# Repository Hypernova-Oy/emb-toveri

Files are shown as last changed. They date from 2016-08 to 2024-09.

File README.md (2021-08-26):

# emb-toveri
Weatherproof embedded user authenticator and authorizator device

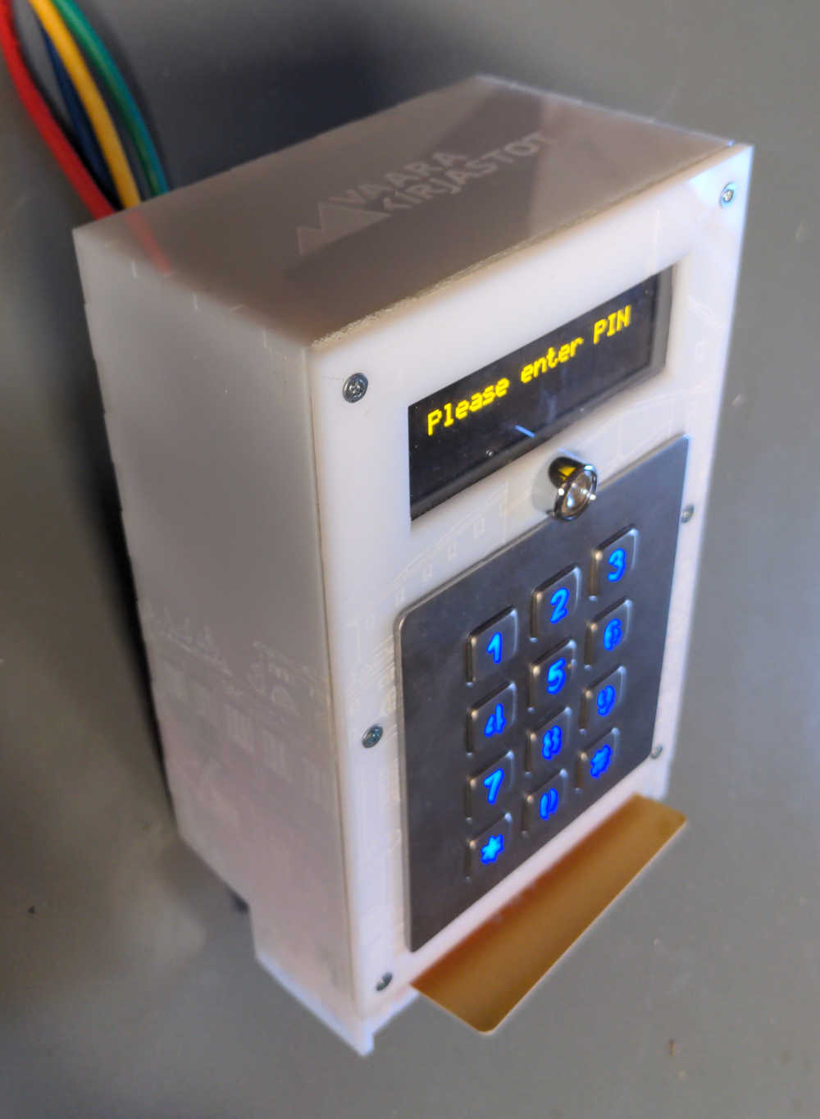
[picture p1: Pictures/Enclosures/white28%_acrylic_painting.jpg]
Toveri_PIN_entry


## Skills needed to build a working Toveri

From front-end to backend

- [GNU gettext](https://www.gnu.org/software/gettext/)
- [Perl](https://www.perl.org/)
- [REST API](http://www.restapitutorial.com/)
- [HiPi](http://raspberrypi.znix.com/hipidocs/)
- [Swig](http://www.swig.org/papers/Perl98/swigperl.htm)
- [C](http://www.cprogramming.com/)
- [SPI](https://en.wikipedia.org/wiki/Serial_Peripheral_Interface_Bus)
- [Ansible](http://docs.ansible.com/)
- [Raspberry Pi](https://www.raspberrypi.org/)
- [Linux](https://www.linuxfoundation.org/)
- [KiCad](http://kicad-pcb.org/)
- [Blender](https://www.blender.org/)
- [Soldering](https://www.youtube.com/watch?v=vIT4ra6Mo0s)
- [Electronic assembly](https://duckduckgo.com/?q=genuino+starter+kit&t=canonical&ia=products)

## Estimated steps to production

* Ordering components from various suppliers (500-600€)
* Assembly of the PCB
* Soldering the PCB
* Making the cabling
* Disassembling and cleaning the 3D print
* Assembling the cables and components to the 3D-printed railing and enclosure.
* Installing Raspbian to the Raspberry Pi
* Setting up internet/network access
* Accessing device via remote maintenance connection
* Configuring barcode reader by reading control codes by hand.
* Installing software
* Configuring software and Server REST API
* Running hardware diagnostics
* Running software diagnostics
* Planning the deployment location
  - Proper accessible position
  - Network access
    - Toveri has a remote maintenance connection using ssh, typically this requires some firewall rules to allow inbound traffic to Toveri's port :TCP22
    - Toveri needs access to the Koha's REST API, typically at port :TCP443
    - Additionally a monitoring solution, such as Zabbix, needs extra inbound/outbound ports to be forwarded. This is outside the scope of this project.
  - Power utility access
  - Maximum distance between the exterior barcode reader and Raspberry Pi is 4m of cable.
  - Safe location for the Raspberry Pi in the interior space.
  - How to attach the device to the exterior wall?
* Executing the deployment plan
* Monitoring performance and logs
* Getting reports of device usage
* Maintenance

## Documentation

* Blender/README.md: Instructions on how to read the electronic enclosure and connection railing schematics.

* KiCad/README.md: Instructions on how to read the electronic diagrams.

* ASSEMBLY.md: Component manifest and supplier list.

* [more here](Documents/)

## Some pics about the finished Toveri

Previous enclosures
Old models

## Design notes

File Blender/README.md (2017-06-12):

In this directory:
------------------

Blender models and measurements of the electronic enclosure and connection railings.
Each component is on its own layer to easily identify needed components.

Uses the excellent MeasureIt-plugin for Blender. Enable it before loading these schematics.

Then go to the MeasureIt-submenu and show measurements.

Toveri3D_printable.blend Toveri3D_printable.stl toveri.blend

FILES:
  Toveri3D_printable.stl contains all the pieces you need. All the separate pieces are readily assembled to be 3D printed.
  Author recommends Shapeways.com and their "White Strong and Flexible"-material for verified results.

  toveri.blend is the master 3D-model with all relevant components modelled.
  It helps a lot when designing the interior space usage.

  screw\ profiles.blend contains the https://en.wikipedia.org/wiki/ISO_metric_screw_thread profiles used in the
  model to print the screw threads. Screw threads help a lot when assembling all the components.

  Other *.blend-files are legacy models and are preserved for historical purposes. They should be fully usable as well,
  if you for some reason prefer older designs.

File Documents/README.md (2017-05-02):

This directory contains various documents related to the lifecycle of emb-toveri.

- Enclosure_1550K-26634.pdf
  The schemtic of the electronic enclosure where Toveri assembled into. Is missing the barcode guide, but
  it only adds ~3cm of extra height.

- DatalogicGryphonGFS4400ReferenceManual820049614RevC.pdf
  Reference manual for programming and using the barcode reader

- barcodeReaderManualConfigurationCodes.png
  You must manually configure the communication protocol for each barcode reader. Other aspects are automatically
  configured whenever Toveri boots.

- Physical_install_FI.odt
  A case example of how to install Toveri to the Eno library.
  Maybe some day will be a complete physical installation guide.

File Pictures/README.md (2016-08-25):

In this directory:
------------------

All images used.

Including printable logos and instructables.

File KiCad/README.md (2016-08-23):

In this directory we present the KiCad electronic schematics you need to assemble this device.

- toveri-directory has the master schematics for all the needed hardware components.

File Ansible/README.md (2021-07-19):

# Toveri software installation and management.

## 0. Prepare the central controller

Toveri-network is managed from one central controller. It automates software provisioning for the Raspberry PIs and management of configuration.

0. Choose a location for your central controller. For testing and assembly purposes it can be a local PC, or a virtual server in the cloud, or anything in between.

1. Install Ubuntu

2. Get the source code

`$> git clone https://github.com/Hypernova-Oy/emb-toveri.git`
`$> cd emb-toveri/Ansible`

3. Install the central controller

`$> sudo bash makefile.sh`

## 1. Provisioning a Raspberry PI

### Prepare the operating system

1. Install Raspbian lite.

2. Run the ansible_slave_driver.sh.gpg in the Raspberry Pi. (see the next step)

### Provision the software from the central controller

#### 1. Add a new Toveri to the central controller

`ansible-playbook -vvvv toverit_provision_new.playbook`

or if you want to provide the configuration from the CLI

`ansible-playbook -vvvv toverit_provision_new.playbook -e max_toveri_port=53518 -e toveri_organization_name=vaara -e toveri_name=liperi`

#### 2. Edit the new configuration and the new vault

#### 3. Run the bootstrap-script in the Raspbian

Copy the encrypted ~/secret/ansible_slave_driver.sh.gpg to the destination Raspbian OS, and run it there, to make the Raspian connect to the central controller.

#### 4. Provision with Ansible

`ansible-playbook toverit.playbook`

## 2. Managing the infrastructure

1. Edit Ansible configuration files

2. Provision with Ansible

`ansible-playbook toverit.playbook`

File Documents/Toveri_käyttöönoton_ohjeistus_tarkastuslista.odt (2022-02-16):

Toveri:n käyttöönoton ohjeistus ja tarkastuslista

# Koha-asennuskohtaiset yhteiset pelisäännöt

Kun Koha-asennuksessa päätetään siirtyä omatoimiaikaan, on sovittava yhteisistä omatoimen pelisäännöistä. On tärkeää pyrkiä yhteisiin käytäntöihin. Tämä on kaikista selkeintä asiakkaillemme, halki kuntarajojen.

Toveri käyttää Kohan itsepalveluoikeuden tarkastusrajapintaa,

- /api/v1/borrowers/ssstatus

joka parametroidaan Kohassa järjestelmäasetuksilla ‘SSRules’ ja ‘OpeningHours’. Toveri noudattaa siis Kohan säädöksiä, ja pelkästään muistaa kävijöiden käyttöoikeustilanteen.

Asetukset on dokumentoitu Kohan pääkäyttäjätyökalussa.

# Kirjaston fyysinen laitteen asennus

Toverin asennus vaatii onnistuakseen usean toimijan yhteistyötä. Monta asiaa pitää huolehtia ennen Toverin asentamista kohteeseen. Ennakkoon asioiden hoitaminen on oleellista, koska avainhenkilöt eivät ole aina tavoitettavissa, tai voivat äkillisen syyn takia olla estyneitä, asennusajankohdassa. Lisäksi asioiden hoitaminen paikan päällä lisää Toveri-asentajan työmäärää asennuspaikassa ja voi viivästyttää asennuksen monipäiväiseksi.

Asennuksen valmistelussa kannattaa ottaa hyvät valokuvat asennuskohteesta. Videopuhelun avulla saa hyvän käsityksen asennuskohteesta ja oikeiden asennuspaikkojen valinta onnistuu sitäkin kautta. Valokuviin tehtyjen merkintöjen avulla on helppo kommunikoida asennus/työtarpeet kaikille osapuolille. Turha matkustaminen asennuskohteisiin on kallista ennenkaikkea työn tilaajalle.

## Asennuspaikka

Ulkopuolen asennuspaikan pitää olla esteettömästi saavutettava, mistä esim pyörätuolilla on mahdollista päästä avatusta ovesta sisään järkevässä ajassa. Asennuspaikan ei tarvitse olla suojassa kosteudelta, sillä Toveri on vedenpitävä ylhäältä ja sivuilta tulevaa kosteuskuormaa vastaan.

Katso Läpiviennit-kohdsta rajoitteet paikan valintaan.

## Älylaitteen sijainti

Sisäpuolelle asennettava älylaite (Raspberry Pi) on laitettava sellaiseen paikkaan, missä asiakkaat eivät pääse helposti sitä räpläämään. Älylaite on suojattu helpolta sorkkimiselta, mutta on mahdollista hakkeroida Älylaite poistamalla muistikortti, muokkaamalla sitä ja asettamalla se takaisin paikoilleen.

Älylaitteen ja Toverin välinen maksimietäisyys on 5m RJ45-kaapelia, koska tällöin voidaan käyttää yksinkertaista kaapelointia eikä erillisiä signaalinvahvistimia tarvita.

## ATK-pistoke ja kaapelin veto talojakomoon

Toveri tarvitsee yhden RJ45-pistokkeen (ATK-pistoke), joka pitää kytkeä talojakomon reitittimeen. Sähkömies asentaa nämä yhdessä kirjaston edustajan kanssa sovittuun paikkaan lähelle Toverin älylaitetta.

## Verkkovirtapistokkeet

Toveri tarvitsee verkkovirtapistokkeen. Sähkömies asentaa nämä yhdessä kirjaston edustajan kanssa sovittuun paikkaan lähelle Toverin älylaitetta. Tarvittaessa voidaan käyttää jatkojohtoa.

## Läpiviennit

Rakennuksen ulkoseinästä pitää porata 25mm halkaisijalla oleva läpivienti sisätilaan Toverin kaapelointia varten. Läpivienti tulee ulkoseinän puolelta mitattuna 115cm korkeudelle lattiasta/maasta. Läpiviennin tekemisessä pitää huomioida helppo sisäpuolen peitettävyys kaapelikotelolla tai muu tapa verhoilla rumat jäljet.

Lisäksi on tärkeää porata läpivienti siten, että se kallistuu alaspäin ulkoseinän puolelle pari astetta, jolloin sadevesi ei pääse valumaan läpivientiä pitkin rakenteisiin. Lisäksi sähköputken ja seinän välinen rako on syytä tiivistää tiivistysmassalla.
Läpiviennin sisälle asennetaan 25mm halkaisijalla oleva sähkö/asennusputki, joka tulee 25mm ulkoseinästä ulospäin, ja 0mm sisäseinästä ulospäin.

Toveri asetetaan sähköputken päälle siten, että putken pää menee Toverin keskiosasta sisäpuolelle, muodostaen vesitiiviin liitoksen.

## Sähkölukkokytkentä

Toveri ohjaa sähkölukkoa ulkoisen releboksin kautta, josta on valmiina ulkona kaksi merkattua piuhaa, joihin sähkölukko kytketään. Toveri sulkee releen ohjaaman potentiaalivapaan virtapiirin oven avaamisen merkiksi.

Sähkölukkokytkennässä pitää sopia sähkölukon toimittajan kanssa:

- Vastaako sähkölukon toimittaja vai Toveri, omatoimikirjaston sähkölukittavien ovien auki pitämisestä normaaleina aukioloaikoina?
- Antaako Toveri sähkölukolle avaussignaalin, vai pitääkö Toverin pitää ovirelettä suljettuna niin kauan kuin sähkölukittuja ovia halutaan pitää auki?

## Kaapeleiden kotelointi

Kaapeleille pitää suunnitella sisäpuolelle reitti miten ne viedään Älylaitteelle. Reitti pitää pystyä koteloimaan tai verhoilemaan siististi.

Kaapelikotelon läpimitoiksi riittää 30x10mm, tyypillisesti 4m kaapelikoteloa riittää asennuskohdetta kohden.

## Älylaitteen verhoilu

Älylaitteen ympärille muodostuu valtava piuha- ja muuntajahärdelli. Se on syytä verhoilla, esim. nätilla IKEA:n kaapilla tai puisella verhoilulevyllä. Älylaitteelle on tarpeellistä päästä tekemään huoltotoimenpiteitä, joten verhoilu/kaappi pitää olla avattavissa.

Usein verhoilua pääsee suunnittelemaan vasta sitten kun Toveri on jo asennettu. Voi olla vaikea arvioida mihin mm. tilatut pistokkeet tarkalleen asentuvat.

## Palomuuriavaukset ja etähuoltoyhteys

Älylaitteesta pitää saada muodostettua yhteys Koha-palvelimen porttiin :TCP443 asiakkaan omatoimikelpoisuuden tarkistamiseksi.

Älylaitteesta pitää saada muodostettua yhteys julkiseen internetiin porttiin :TCP22 Toveri-keskuspalvelimen huoltoyhteyttä varten. Älylaite avaa käänteisen huoltotunnelin käyttäen turvallisia ssh-avaimia, jota pitkin keskuspalvelimelta saadaan muodostettua yhteys.

Älylaite tarvitsee normaalin pääsyn internetiin erilaisten ohjelmisto-, sekä käyttöjärjestelmäpäivitysten hakemiseksi.

Toveri ei tarvitse kiinteää (julkista tai sisäverkon) IP-osoitetta, mutta sellainen voidaan tarvittaessa asettaa paikallisten verkkoliikennekäytänteiden mukaisesti.

Palomuuriavauksista on syytä huolehtia hyvissä ajoin, sillä niiden toimivuudessa on ollut historiallisesti haasteita.

Palomuuriavaukset pitää testata etukäteen, tai ainakin varoittaa verkkoliikenteestä vastaavia tahoja asennusajankohdasta, että vastaavat puhelimeen.

# Kirjastokohtaiset Toverin asetukset

Koha-asennus (organisaatio) -kohtaisten määrittelyjen lisäksi, jokainen Toveri pitää parametroida toimimaan kirjastokohtaisesti optimaalisesti.

## Toverin kotelon ja kaiverrusten valinta

Jokaiselle Toverille tehdään meidän tehtalla oma kotelo. Asiakas voi valita yhteistyökumppanimme materiaalipankista:

https://cotter.co/materials/

haluamansa värin ja materiaalin, seuraavin rajoituksin:

- Huom, neon-acrylic on läpinäkyvää akryyliä.

- Ulkotiloihin vain polykarbonaatti tai akryyli, paksuus 3mm.
- Sisätiloihin käy myös puiset materialit

Toveriin saa omat kaiverrukset. Yksinkertaiset logot kuuluvat tarjoukseen.
Koteloon voidaan kaivertaa esimerkiksi Akseli Gallen Gallelan Kalevala-aiheisia maalauksia tai joku teidän kirjastollenne tärkeä asia, johon teiltä tekijänoikeus löytyy.

Jos kaiverrukset ovat erityisen vaativia, pyydetään lisähintaa tarjouksen mukaisesti.

Toimita logot ja kuvat mieluiten vektorigrafiikkaformaatissa. Tarvittaessa me hoidamme kuvien muuntamisen kaiverrusmuotoon, sekä yksinkertaistamme niitä laserkaiverrukseen sopivaksi.

Esimerkkejä kaiveruksista ja koteloista löytyy täältä:
https://github.com/Hypernova-Oy/emb-toveri/tree/master/Pictures/Enclosures

Kotelon laserleikkausprofiili löytyy täältä:

https://github.com/Hypernova-Oy/emb-toveri/blob/master/FreeCAD/Toveri-3mm-acrylic.svg

## Sähkölukon avaussignaalin pituus

Riippuen siitä pitääkö Toverin pitää sähkölukko auki, vai antaako Toveri signaalin taloautomaatio-ohjelmistolle, pitää määrittää miten pitkään Toverin ovenavausrele antaa ohjaussignaalia sähkölukolle.

Jos Toveri ohjaa sähkölukkoa suoraan, ohjaussignaalin pituus on se aika kun sähkölukot pysyvät auki hyväksytyn asiakkaan tunnistautumisen jälkeen.

Jos Toveri antaa ohjaussignaalin taloautomaatio-ohjelmalle, lyhyt 1000ms impulssi riittänee.

ks. kappale “Sähkölukkokytkentä”

## Omatoimiajat

Jokaiselle kirjastolle pitää määritellä se omatoimiaika, jolloin Toveri päästää uusia asiakkaita sisään.

Tämä määrittely tapahtuu Kohassa.

Toveri ei aja asiakkaita pois omatoimiajan päätyttyä.

Parempi on mitä vähemmän poikkeuksia omatoimen aukioloajoissa on. Suositellaan, että käytetään säännöllisiä viikkoaukioloja, joka päivä, riippumatta erikoisista juhlapyhistä.

## Toveri-käyttäjä Kohassa

Jokainen Toveri tarvitsee laitekohtaisen käyttäjä/asiakastilin Kohassa.

Käyttäjälle pitää määritellä seuraavat asiat:

- Asiakaslaji on automaatti tai vastaava
- Käyttäjätunnus on mallia ‘toveri.KIRJASTOKOODI’
- Toveri -käyttäjätilin kirjasto on asetettu oikein.
- Käyttäjätilin API-avain on luotu ja toimitettu Toveri-asentajalle. API-avaimen voi luoda virkailijatyökalussa osoitteessa [Etusivu › Asiakkaat › API-avaimet] ‘/cgi-bin/koha/members/apikeys.pl’
- Käyttäjätilille on annettu oikeus ‘borrowers.get_self_service_status’
- Omatoimikirjastopisteelle on asetettu viikoittaiset aukioloajat Kohan järjestelmäasetukseen ‘OpeningHours’.

# Kirjastokohtaiset omatoimipalvelun muut asiat

Tässä kappaleessa kuvataan Toveri-asennuksen ja määrittelyn ulkopuolisia asioita, joita kirjaston on syytä ottaa huomioon asennuskohteessaan.

## Miten asiakkaat ajetaan pois omatoimiajan päätyttyä?

Käytetäänkö aikaohjattuja valoja?
Onko kuulutuksia?

Missä aikaohjauksien aikatauluja ylläpidetään? Käyttöönoton tarkastuslomake

Ohessa on listattu kuvatut toimenpiteet, joista pitää huolehtia, että Toveri saadaan onnistuneesti asennettua.

Taulukot noudattelee RACI (https://fi.wikipedia.org/wiki/RACI)-tapaa.

## Taulukon lyhenteiden selitykset ja yhteystiedot

R - “Kuka vastaa/tekee”-sarake. Kuka vastaa asian hoitamisesta tai delegoinnista käytännön tasolla.

A- “Kuka on vastuussa” -sarake.

C - “Ketä on konsultoitava” -sarake. Keneltä on kysyttävä mielipide.

I - “Ketä on tiedotettava” -sarake. Kenelle on kerrottava työn edistymisestä.

Rooli | Kuvaus | Vastuuhenkilön yhteystieto
Koha | Kohan pääkäytäjä
Toveri | Toverin toimittaja
KH | Kiinteistöhuolto
PH | Projektinhallinta
Ovi | Sähköovien toimittaja
ICT | Verkko- ja tietoliikennetuki

## Laitteen asennus

Tehtävä | R | A | C | I
Onko Kohaan parametroitu omatoimen käyttösäännöt? | Koha | PH | Kir
Miten meni?
Onko Toverin asennuspaikka valittu ulkopuolelle? Onko se saavutettavissa? Onko se esteettinen? | Kir Toveri | PH | KH
Miten meni?
Onko Älylaitteen paikka valittu sisääpuolelle? Onko se epäsaavutettavissa? Yltääkö kaapelit Toverista Älylaitteeseen? | Kir Toveri | PH | KH
Miten meni?
Onko ATK-pistoke Älylaitteelle ja verkkokaapelin veto talojakomoon tilattu? | KH | PH
Miten meni?
Onko ATK-pistoke ja verkkopiuha asennettu? | KH | PH
Miten meni?
Onko verkkovirtapistoke tilattu? | KH | PH
Miten meni?
Onko verkkovirtapistoke asennettu ja tuleeko virtaa? | KH | PH
Miten meni?
Onko läpiviennit tilattu? | KH | PH | Toveri
Miten meni?
Onko läpiviennit toteutettu? | KH | PH
Miten meni?
Onko sähkölukkokytkennästä sovittu sähkölukon toimittajan kanssa? | Ovi | PH | Toveri KH
Miten meni?
Onko kaapeleiden reitti tiedossa? Onko kotelointi suunniteltu? | Toveri | PH | KH Ovi
Miten meni?
Onko verhoilu suunniteltu? | Kir | PH | KH Toveri
Miten meni?

Onko verhoilu tehty? | KH tai Toveri | PH
Miten meni?
Onko palomuuriavaukset tilattu? | Kir | PH | Toveri
Miten meni?
Onko palomuuriavaukset tehty? | ICT | PH
Miten meni?
Onko palomuuriavaukset testattu? | Kir | PH | Toveri ICT
Miten meni?
Onko asennusajankohta sovittu yhdessä sidosryhmien kanssa? | Toveri | PH | Kir, ICT, Ovi, KH
Miten meni?
Asennuksen toteuttaminen | Toveri | PH | Kir, ICT, Ovi, KH
Miten meni?
Koulutuksen järjestäminen | Toveri | PH | Kir
Miten meni?

## Kirjastokohtaiset Toverin asetukset

Tehtävä | R | A | C | I
Miten pitkään sähkölukkoa pidetään avoinna? | Toveri | PH | Ovi
Miten meni?
Mitkä ovat toimipisteen aukioloajat? | Koha | PH | Kir
Miten meni?
Kohaan on lisätty Toverille oma asiakas/käyttäjätili kohdan Toveri-käyttäjä Kohassa mukaisesti. | Koha | PH | Kir | Toveri
Miten meni?

## Kirjastokohtaiset omatoimipalvelun muut asiat

Tehtävä | R | A | C | I
Miten asiakkaat ajetaan pois omatoimiajan päätyttyä? | Toveri | PH | Ovi
Miten meni?

# Takuuvaiheen vastuut ja yhteystiedot

RACI-taulukot noudatavat samaa kaavaa kuin kappaleessa #Käyttöönoton tarkastuslomake.

Yhteystiedot samat kuin kohdassa #Käyttöönoton tarkastuslomake.

Tehtävä | R | A | C | I
Toveri toimii oikein: Lukee asiakkaan tunnisteen ja piippaa merkiksi onnistuneesta lukukerrasta. Näyttää tietoja näytöllä Ovenavausrele “napsahtaa” kun ovenavaussignaali annetaan Kirjaston henkilökunta ilmoitusvelvollisia havaituista puutteista. | Toveri Kir | Toveri | Kir | Kir Toveri
Verkkoyhteys toimii: Etäyhteys Toveriin saada muodostettua Toveri saa poimittua päivän blokkilistan Koha-palvelimelta Toveri saa reaaliaikaiset käyttöoikeustiedot Koha-palvelimelta | ICT | Kir | Toveri
Sähköä on tarjolla | KH | | | Toveri
Koha on parametroitu oikein: Järjestelmäasetukset ok Asiakkaan luvat ja tiedot päivitetty asiakastiliin Koha vastaa rajapintakutsuihin ja toimittaa blokkilistan | Koha | Kir | | Toveri

## Toveri-vikaselvitysprosessi

Tyypillisesti vikatilanteessa toimitaan seuraavanlaisesti.

1. Virkailija tai kirjaston käyttäjä huomaa vikatilanteen.
2. Ilmoitetaan Hypernovan Toveri-yhteyshenkilölle sähköpostilla, tai hätätilanteessa puhelimitse.
3. Toveri-yhteyshenkilö tarkastaa tilanteen etäyhteyden kautta ja ajaa laitediagnostiikat, yhdessä kirjaston yhteyshenkilön kanssa. Selvitetään onko vika Toverissa vai jossain muualla ja mikä on vian vakavuusaste.
4. Jos etäyhteyden kautta vikaa ei saada korjattua, käydään laite huoltamassa tai vaihtamassa uuteen.

# Versiohistoria

2018-11-15 – Ensimmäinen versio

2019-06-25 – Lisätty “Kirjastokohtaiset Toverin asetukset → Toveri-käyttäjä Kohassa → ‘OpeningHours’”
2020-09-08 – Laajennettu läpivienti 30mm
2020-10-29 – Custom-kotelointiohjeet lisätty

2022-02-16 – Palautettu läpiviennin halkaisija 25mm. Täsmennetty läpiviennin ohjeita. Pieniä korjauksia.

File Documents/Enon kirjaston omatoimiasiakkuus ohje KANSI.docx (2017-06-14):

Ongelma- ja hätätilanteen

Kirjaston käyttöön liittyvissä ongelmatilanteissa ota yhteyttä mihin tahansa avoinna olevaan Vaarakirjastojen toimipisteeseen puhelimitse. Puhelinnumerot löytyvät mm. lainaus-palautusautomaatin kyljestä. Toivomme, että omatoimiajalla ilmenneistä ongelmista kerrotaan myös Enon kirjaston henkilökunnalle joko henkilökohtaisesti palveluajalla, kirjoittamalla palvelutiskillä olevaan viestivihkoon tai sähköpostitse: enonkirjasto@jns.fi


Hätätilanteet

Yleinen hätänumero 112
Kiinteistönhuollon päivystys 044 576 7402

Yhteystiedot

Enon kirjasto
050 469 8722 / palvelutiski
enonkirjasto@jns.fi

Joensuun pääkirjasto
050 406 5992 / lainausosasto
kirjasto@jns.fi

www.vaarakirjastot.fi

ASIOINTI OMATOIMIAIKAAN

# ENON KIRJASTOSSA

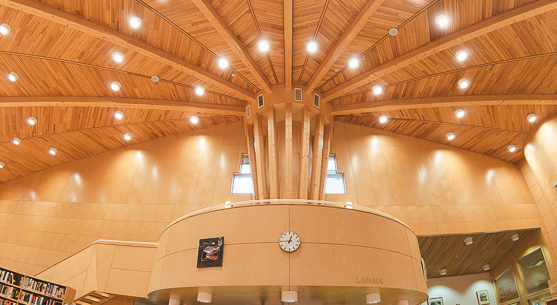
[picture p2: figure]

OMATOIMIAIKA KULKUKORTILLA

- ma-pe 07.00 – 20.00
- la ja su 08.00 – 16.00

PALVELUAIKA

- maanantai ja torstai

13.00 – 19.00

- tiistai, keskiviikko

ja perjantai 10.00 – 16.00

- aattoina 10.00 – 15.00

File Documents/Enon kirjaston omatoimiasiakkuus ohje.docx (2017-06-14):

# Omatoimiasiakkuus

Enon kirjastossa voi asioida omatoimiaikaan, eli

silloinkin kun henkilökunta ei ole paikalla.

Omatoimiasiakkaan tulee hyväksyä omatoimiasiakkuuden ehdot ja allekirjoittaa asiakassopimus. Asiakassopimus tehdään palveluaikaan kirjastohenkilökunnan työskennellessä Enon kirjastossa.

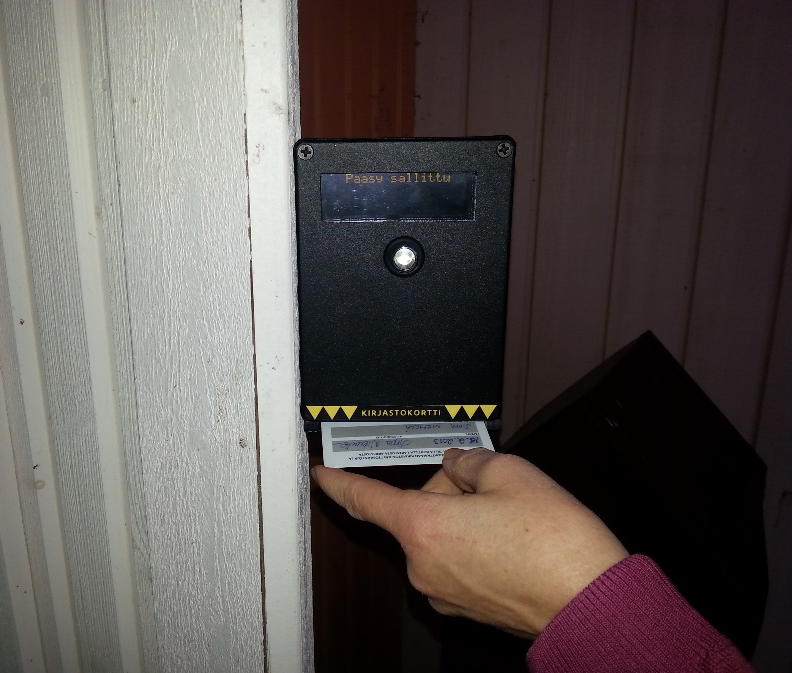
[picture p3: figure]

Asiakkaalla tulee olla voimassaoleva Vaara-kirjastojen kortti eikä asiakastiedoissa saa olla kirjaston käyttöön liittyviä rajoituksia. Alle 18 vuotiaiden asiakassopimukseen edellytetään myös huoltajan allekirjoitus.

Kun asiakassopimus on allekirjoitettu

ja omatoimiasiakkuuden oikeus tallennettu

kirjastojärjestelmään,

kirjaston ovi aukeaa kirjastokortilla

(viivakoodipuoli ylöspäin).

Omatoimiaika tarkoittaa sitä,

että henkilökunta ei ole palvelemassa,

neuvomassa ja opastamassa kirjastossa.

Lainaus- ja palautusautomaatin käytön opettelu

ja muu tutustuminen kirjastoon tapahtuu

palveluajalla.

Omatoiminen asiointi Enon kirjastossa

on mahdollista maanantaista perjantaihin klo 07:00-20:00.

Viikonloppuisin (lauantaina ja sunnuntaina) omatoimiasiointi on mahdollista klo 08:00-16:00 välisenä aikana.

Omatoimiajan päätyttyä ma-pe klo 20:00 ja la-su klo 16:00 hälytysjärjestelmä kytkeytyy automaattisesti päälle. Rakennuksesta on poistuttava ennen omatoimiasioinnin päättymisaikaa, sillä aiheettomista hälytyksistä peritään niiden aiheuttajalta maksu.




Kirjastossa on tallentava kameravalvonta.

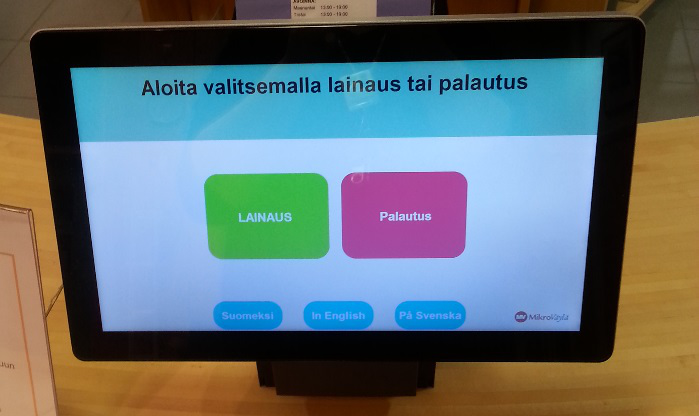
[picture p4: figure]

# Lainaus- ja

# palautusautomaatin käyttö

Automaatilla lainaamista varten

tarvitaan voimassa oleva kirjastokortti.
Palautettaessa kirjoja, kirjastokorttia ei tarvita.

Lainaus- ja palautusautomaatin käyttö on helppoa: se neuvoo koko ajan, mitä seuraavaksi tulee tehdä. Lue huolellisesti näytöllä olevat ohjeet kussakin vaiheessa.

Kirjastoaineistossa olevan viivakoodin tulee olla ylöspäin. Muuten koodin suunnalla ei ole väliä (sen voi laittaa myös poikittain tai vinottain). Viivakoodi on useimmiten niteen takakannessa, mutta voi olla myös etukannessa, tai takakannen sisäpuolella.

Kirjaston viivakoodit ovat aina tarroja ja niissä lukee kirjaston nimi.

HUOM! Kirjan kanteen painettu ISBN-tunnus ei ole kirjaston viivakoodi.

Mikäli aineiston viivakoodi ei toimi kun yrität lainata:
merkitse oman kirjastokorttisi numero sekä aineiston nidenumero (=viivakoodiraidan alla oleva esim. 167–alkuinen numerorivi) palvelutiskillä olevaan lomakkeeseen.

Lainattu aineisto on aina palautettava joko palveluaikana palvelutiskillä tai omatoimiajalla automaatin kautta. Palautusluukkua ei ole. Älä jätä palauttamatonta lainaa omatoimiajalla kirjaston pöydälle!

Mikäli aineiston viivakoodi ei toimi kun yrität palauttaa automaatilla:

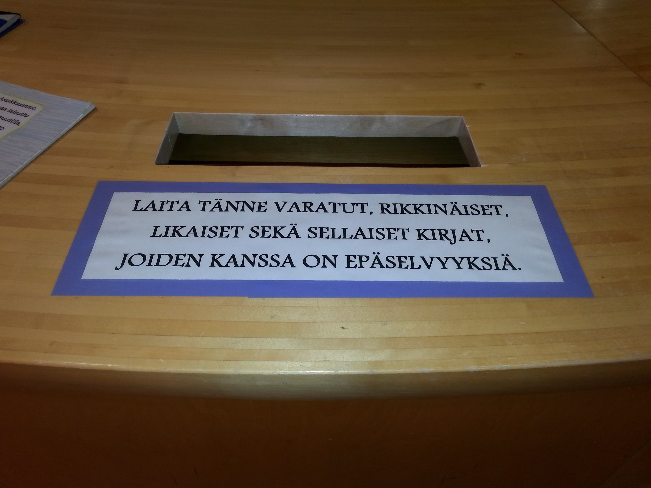
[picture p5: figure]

laita palautettava aineisto automaatin

vieressä olevasta aukosta palvelutiskin

alla olevaan lukolliseen palautuslaatikkoon.

Olet vastuussa lainasta siihen saakka kunnes

se on palautettu kirjastojärjestelmän kautta.

Mikäli palautus ei onnistu ja palautuspäivä on eräpäivä,

uusi laina joko netissä omilla tunnuksillasi tai

soita johonkin auki olevaan Vaara-kirjastojen

toimipisteeseen.

Puhelinnumeroita on automaatin yläpuolella, jaossa kirjastolla ja netissä ja tämän ohjeen takakannessa.

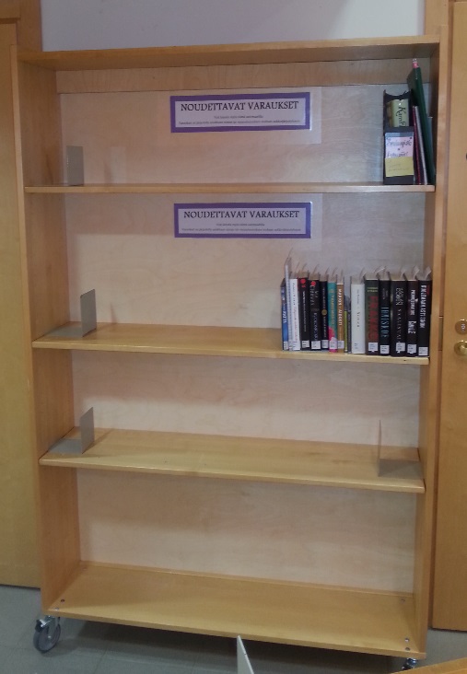
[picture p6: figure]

# Varaukset

Varattu aineisto on varatulle aineistolle merkityssä hyllyssä

palvelutiskin vieressä.

Varaukset ovat hyllyssä järjestettynä asiakkaan sukunimen

tai varaustunnisteen mukaiseen aakkosjärjestykseen.

Mikäli et halua, että varaamasi aineisto odottaa omalla

nimelläsi muiden asiakkaiden näkyvillä, laita itsellesi

varaustunnus Vaara-kirjastojen nettisivuilla.

Varaustunnuksen voi vaihtaa välilehdellä käyttäjätiedot,

kohdassa varaustunnus.

Virkailija voi myös vaihtaa tunnuksen asioidessasi kirjastossa palveluaikaan.

# Lehdet

Varhaisjakeluna tulevat sanomalehdet Karjalainen,

Helsingin Sanomat sekä Pielisjokiseutu löytyvät

omatoimiaikaan kirjaston pääsisäänkäynnin tuulikaapista. Toivomme, että uusimmat sanomalehdet laitetaan omatoimiajallakin siististi omille paikoilleen lehtilukusalin kaapinoviin.

Aikakauslehdet jaetaan kirjaston lukolliseen postilaatikkoon, josta henkilökunta noutaa ja käsittelee päiväpostin.

Huom!
Valaistus lehtilukusalissa toimii liiketunnistimen perusteella. Mikäli valot sammuvat yllättäen,
pieni liikehdintä sytyttää ne jälleen.

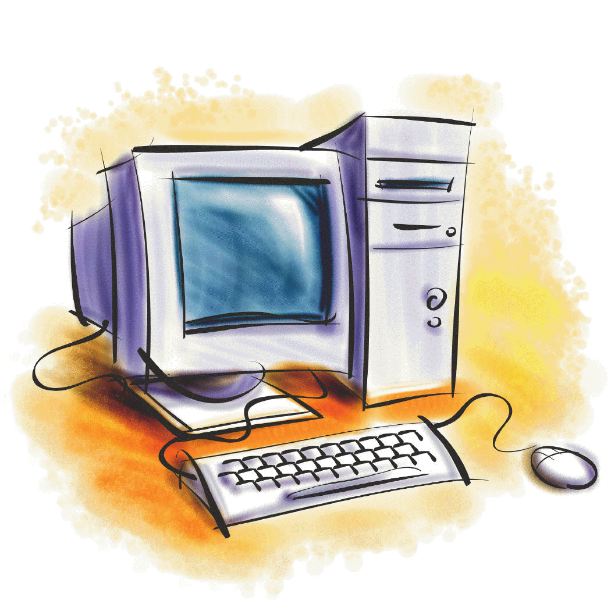
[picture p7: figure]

# Tietokoneet

Kirjaston asiakastietokoneet ovat käytettävissä myös omatoimiaikaan.
Koneista viisi on varattavia koneita ja varauslista löytyy palvelutiskiltä.
Lehtilukusalin konetta ei tarvitse varata. Lähinnä palvelutiskiä

sijaitsevat kaksi konetta on tarkoitettu verkkokirjaston käyttöön sekä

lyhyiden tiedonhakujen tekemiseen, eikä niitä voi varata.

Koneelle voi mennä, jos kukaan ei siinä ole, mutta varaajalla on aina etuoikeus koneen käyttöön. Kaikilla asiakkailla on yhtäläinen oikeus koneiden käyttöön varauksen perusteella.

Kirjastotilassa yleensäkään ei saa syödä eikä juoda ja tämä sääntö pätee myös asiakastietokoneiden äärellä. Tietokonetta käyttävälle on annettava rauha ja yksityisyys.

Kirjastossa on langaton verkkoyhteys.

Yhteyden nimi on kirjasto wlan ja salasana internet.

# Tulostus

Kaikilta tietokoneilta voi tulostaa parvelle johtavien rappusten alla olevalle monitoimilaitteelle.

Mikäli haluat värillisen tulosteen, valitse tulostusvälilehdellä tulostimen ominaisuudet,
-> kuva-asetukset -> ruksi pois kohdasta Xeroxin mustavalko.

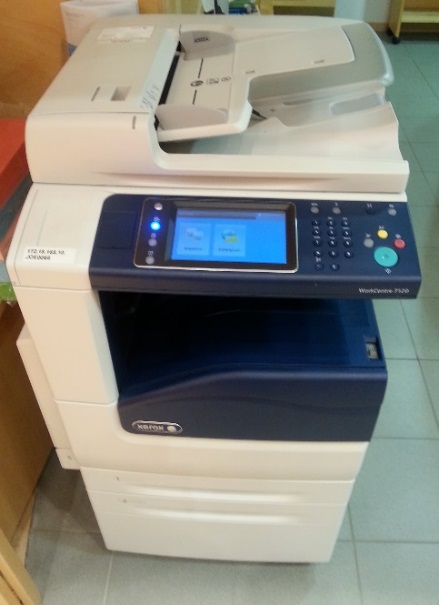
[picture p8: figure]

Tulosteet maksavat:

mustavalkoiset 0,40 € /kpl

värilliset 1,00 € /kpl

# Kopiointi

Kirjastossa voi ottaa omatoimisesti kopioita. Hinnat ovat samat

kuin tulosteissa (ks. yllä).

Omatoimiaikana otetut tulosteet ja kopiot merkitään palvelutiskillä olevaan vihkoon ja maksetaan palveluaikana henkilökunnan ollessa paikalla.

Huom! Monitoimilaitteella pystyy myös skannaamaan (maksuton).

# Asiakas-

Asiakkaiden käytössä olevat wc:t sijaitsevat pääsisäänkäynnin ovelta katsottuna oikealla.

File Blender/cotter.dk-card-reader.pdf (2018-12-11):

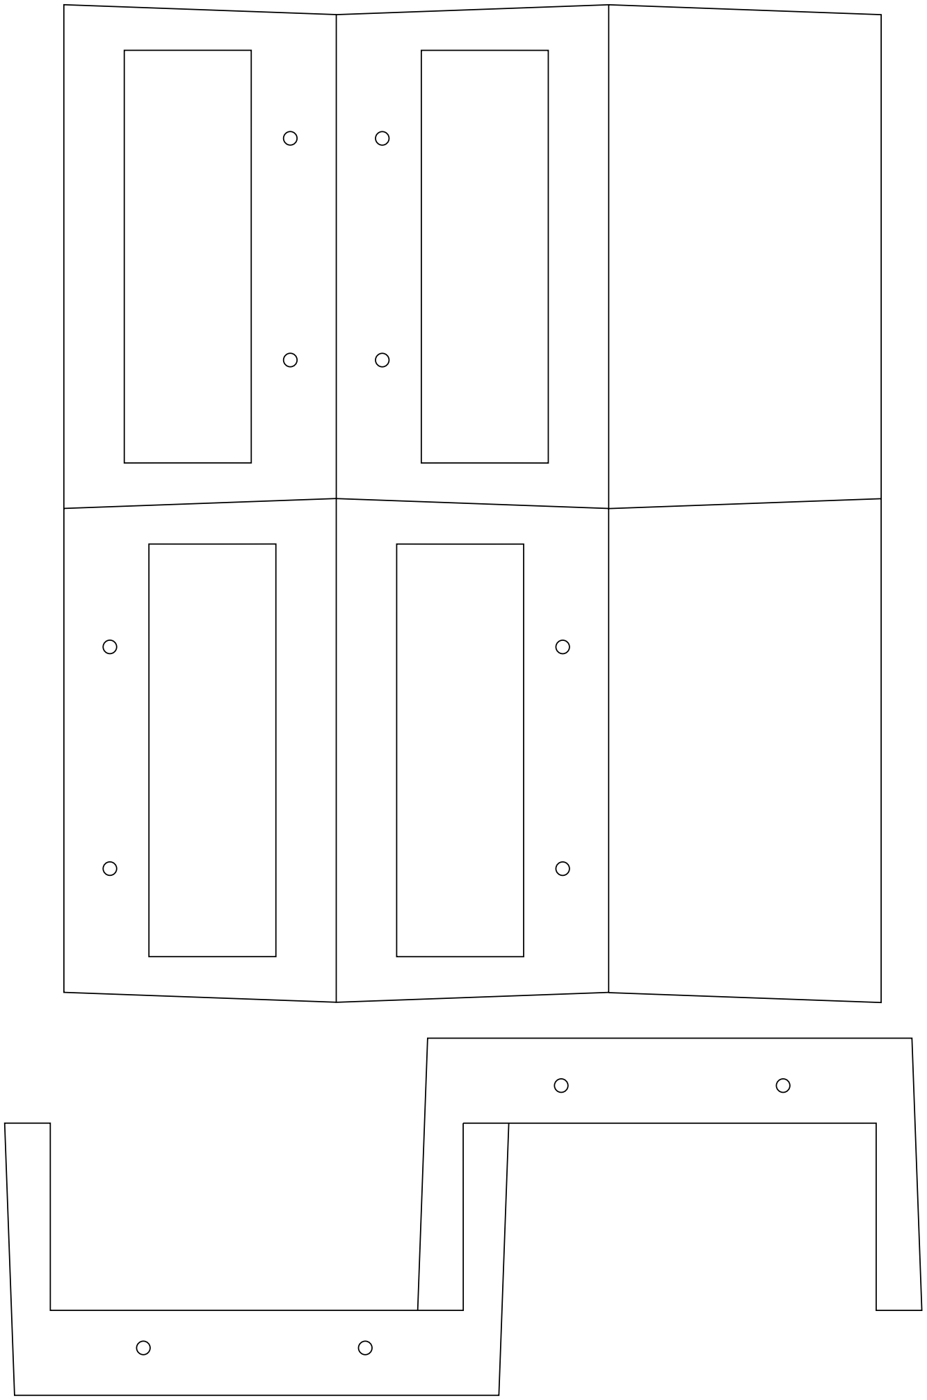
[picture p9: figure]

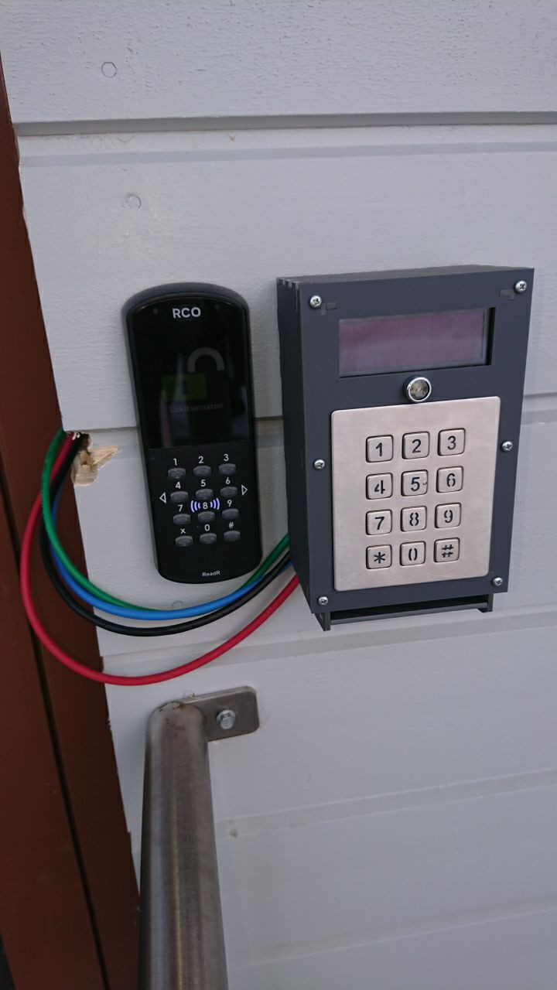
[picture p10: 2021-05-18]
Pictures/Enclosures/matte_gray_front.jpg

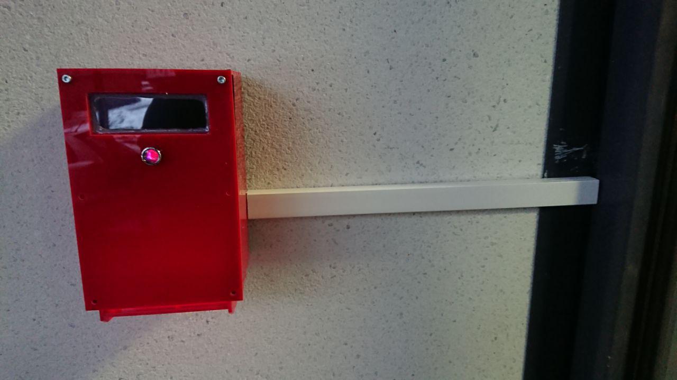
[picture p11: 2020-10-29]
Pictures/Enclosures/red_acrylic_front.jpg

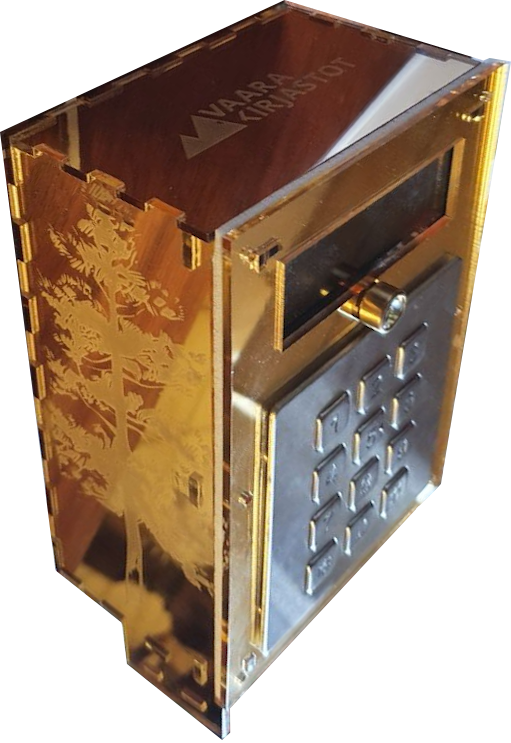
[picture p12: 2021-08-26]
Pictures/Enclosures/gold_acrylic_tree.png

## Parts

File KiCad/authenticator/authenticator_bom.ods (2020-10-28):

Reference | Value | Footprint | Datasheet | ALV0%€ | Manufacturer | Model | Title | Supplier | Length | BodyHeight
C1 | CP | Koha-Suomi:UMW0G101MDD | https://www.mouser.fi/datasheet/2/293/e-umw-1219455.pdf | 0.297 | Nichicon | UMW0G101MDD | Aluminium Electrolytic Capacitors - Radial Leaded 4volts 100uF 85c 5x5 2LS
R4 | 4.7k | Koha-Suomi:Resistor_ThroughHole_6.3x2.3mm_Spacing2.54mm | https://www.mouser.fi/datasheet/2/219/MF-MFS-RK-18760.pdf | 0.231 | KOE Speer | MF1/4DC4701F | Metal Film Resistors - Through Hole 4.7K 1% 100PPM
R1 | 110 | Koha-Suomi:Resistor_ThroughHole_6.3x2.3mm_Spacing2.54mm | https://www.mouser.fi/datasheet/2/219/MF-MFS-RK-18760.pdf | 0.231 | KOA Speer | MF1/4DC1000F | Metal Film Resistors - Through Hole 100ohm 1% 100PPM
R2 | 220 | Koha-Suomi:Resistor_ThroughHole_6.3x2.3mm_Spacing2.54mm | https://www.mouser.fi/datasheet/2/219/MF-MFS-RK-18760.pdf | 0.191 | KOA Speer | MF1/4CCT52R2200F | Metal Film Resistors - Through Hole 1/4 WATT 220 OHM 1%
DS1 | DS18B20+ | Koha-Suomi:TO-92_Inline_Wide | https://www.mouser.fi/datasheet/2/256/DS18B20-370043.pdf | 3.53 | Maxim Integrated | DS18B20+ | Board Mount Temperature Sensors Prgmble Resolution 1-Wire Parasite Pwr
AST1 | AST-1732MR-R | Koha-Suomi:AST-1732MR-R | https://www.mouser.fi/datasheet/2/334/AST-1732MR-R-72511.pdf | 3.5 | PUI Audio | AST-1732MR-R | Speakers & Transducers SPEAKER 32OHM
H10 | HEADER_S_1X04 | Koha-Suomi:Pin_Header_Straight_1x04_Pitch2.54mm | https://www.mouser.fi/datasheet/2/276/0022032041_PCB_HEADERS-158390.pdf | 0.297 | Molex | 22-03-2041 | Headers & Wire Housings VERT PCB HDR 4P TIN PLATING
H8 | HEADER_S_1X03 | Koha-Suomi:Pin_Header_Straight_1x03_Pitch2.54mm | https://www.mouser.fi/datasheet/2/276/0022102031_PCB_HEADERS-158469.pdf | 0.459 | Molex | 22-10-2031 | Headers & Wire Housings VERT PCB HDR 3P GOLD PLATING
H9 | HEADER_S_1X07 | Koha-Suomi:Pin_Header_Straight_1x07_Pitch2.54mm | https://www.mouser.fi/datasheet/2/276/022102074_sd-589973.pdf | 1.52 | Molex | 22-10-2074 | Headers & Wire Housings KK 100 Hdr Flat VERT 20 Au 7Ckt | www.mouser.fi
D1 | D | Koha-Suomi:1N4154TAP | https://www.mouser.fi/datasheet/2/427/1n4154-241332.pdf | 0.135 | Vishay Semiconductors | 1N4154TAP | Diodes - General Purpose, Power, Switching Vr/35v Io/150mA
D2 | D | Koha-Suomi:1N4154TAP | https://www.mouser.fi/datasheet/2/427/1n4154-241332.pdf | 0.135 | Vishay Semiconductors | 1N4154TAP | Diodes - General Purpose, Power, Switching Vr/35v Io/150mA
EC2 | EC2-3TNU | Koha-Suomi:EC2-3TNU | https://www.mouser.fi/datasheet/2/212/KEM_R7002_EC2_EE2-1104574.pdf | 2.42 | KEMET | EC2-3TNU | Low Signal Relays - PCB 3V 2A Dbl Latching LL=3.2mm
RJ2 | RJ45_2xPort | Koha-Suomi:RJ45 dual port - WE-15016137621 | https://katalog.we-online.com/em/datasheet/615016137621.pdf | 3.51 | Wurth Elektronik | 615016137621 | Modular Connectors / Ethernet Connectors WR-MJ Feml Shielded 8P8C Hztl Dual Port
RJ1 | RJ45_2xPort | Koha-Suomi:RJ45 dual port - WE-15016137621 | https://katalog.we-online.com/em/datasheet/615016137621.pdf | 3.51 | Wurth Elektronik | 615016137621 | Modular Connectors / Ethernet Connectors WR-MJ Feml Shielded 8P8C Hztl Dual Port
H6 | HEADER_A_1X07_F | Koha-Suomi:Header-1x7-F (Molex 38-00-1337) | https://www.mouser.fi/datasheet/2/276/0038001337_PCB_RECEPTACLES-159893.pdf | 1.22 | Molex | 38-00-1337 |  | Mouser
H5 | HEADER_A_1X07_F | Koha-Suomi:Header-1x7-F (Molex 38-00-1337) | https://www.mouser.fi/datasheet/2/276/0038001337_PCB_RECEPTACLES-159893.pdf | 1.22 | Molex | 38-00-1337 |  | Mouser
TH1 | Thermistor_PTC | Koha-Suomi:1N4154TAP | https://docs-emea.rs-online.com/webdocs/0f72/0900766b80f72deb.pdf | 15.3 | DBK Enclosures | HPG-2/08-75X35-12-30 | Enclosure Heating Element, 18W, 80°C, 12 → 30 V ac/dc | fi.rsdelivers.com
T1 | Screw_Terminal_01x04 | Koha-Suomi:Terminal 1x4 (Molex-398800304) | https://www.molex.com/pdm_docs/sd/398800304_sd.pdf | 1.16 | Molex | 39880-0304 | Fixed Terminal Blocks LOW PROFILE 5.08 4 A W PROFILE 5.08 4 ASY
DUP2 | Dupont_Cable_3-pin | Koha-Suomi:Bad_board_tag |  | 2 |  | 2.54 pitch 3-wire cable |  |  | 20cm
CC1 | Cabinet_cable_2-wire | Koha-Suomi:Bad_board_tag |  | 5 |  | Cabinet cable 2-wire | Cabinet cable 2-wire |  | 5m
CAT1 | Cat-cable red | Koha-Suomi:Bad_board_tag | ~ | 9.8 | RS PRO | 557-345 | RS Pro Red Cat6 Cable F/UTP LSZH, 5m | fi.rsdelivers.com | 5m
CAT2 | Cat-cable blue | Koha-Suomi:Bad_board_tag | ~ | 9.8 | RS PRO | 557-317 | RS Pro Blue Cat6 Cable F/UTP LSZH, 5m | fi.rsdelivers.com | 5m
J1 | Barrel_Jack | Connectors_Molex:Molex_KK-6410-02_02x2.54mm_Straight | ~ | 3.25 | CIE | CLB-JL-8118 | CIE CLB-JL Series, Cable Mount Jack Adapter[Blank] Socket, 2 Pole, 5A | fi.rsdelivers.com
RPi1 | RPi_GPIO | Koha-Suomi:PI_GPIO_Header_F_2x20 | https://www.mouser.fi/datasheet/2/1/ts0815-31700.pdf | 2.27 | Adafruit |  | 40 Pin Extra Tall Header (Push Fit Version) | thepihut.com |  | 13.5mm
T2 | Screw_Terminal_01x02 | Koha-Suomi:Screw_Terminal_01x02 (Molex) | https://www.mouser.fi/datasheet/2/276/0398800302_TERMINAL_BLOCKS-167600.pdf | 0.648 | Molex | 39880-0302 | Fixed Terminal Blocks 2 CKT TERM. BLOCK 5.08mm
D3 | D | Koha-Suomi:1N4154TAP | https://www.mouser.fi/datasheet/2/427/1n4154-241332.pdf | 0.135 | Vishay Semiconductors | 1N4154TAP | Diodes - General Purpose, Power, Switching Vr/35v Io/150mA
D4 | D | Koha-Suomi:1N4154TAP | https://www.mouser.fi/datasheet/2/427/1n4154-241332.pdf | 0.135 | Vishay Semiconductors | 1N4154TAP | Diodes - General Purpose, Power, Switching Vr/35v Io/150mA
EC1 | EC2-3TNU | Koha-Suomi:EC2-3TNU | https://www.mouser.fi/datasheet/2/212/KEM_R7002_EC2_EE2-1104574.pdf | 2.42 | KEMET | EC2-3TNU | Low Signal Relays - PCB 3V 2A Dbl Latching LL=3.2mm
HS2 | Heatsink | Koha-Suomi:Bad_board_tag | https://www.mouser.fi/datasheet/2/2/Aavid-Board-Level-Heatsinks-Catalog-2018-1507171.pdf | 5.49 | Aavid | 374624B00032G | Heat Sinks Heatsink for Metal/Ceramic BGA Packages, Black Anodized, 35x35x10mm, IC Pkg Size = 35 x 35, Tape #32
HS1 | Heatsink | Koha-Suomi:Bad_board_tag | https://www.mouser.fi/datasheet/2/2/Aavid-Board-Level-Heatsinks-Catalog-2018-1507171.pdf | 5.49 | Aavid | 374624B00032G | Heat Sinks Heatsink for Metal/Ceramic BGA Packages, Black Anodized, 35x35x10mm, IC Pkg Size = 35 x 35, Tape #32
DS2 | DS18B20+ | Koha-Suomi:TO-92_Inline_Wide | https://www.mouser.fi/datasheet/2/256/DS18B20-370043.pdf | 3.53 | Maxim Integrated | DS18B20+ | Board Mount Temperature Sensors Prgmble Resolution 1-Wire Parasite Pwr
R3 | 220 | Koha-Suomi:Resistor_ThroughHole_6.3x2.3mm_Spacing2.54mm | https://www.mouser.fi/datasheet/2/219/MF-MFS-RK-18760.pdf | 0.191 | KOA Speer | MF1/4CCT52R2200F | Metal Film Resistors - Through Hole 1/4 WATT 220 OHM 1%
V1 | +12V | Koha-Suomi:1N4154TAP | ~ | 9.1 | RS PRO | 175-3316 | RS PRO, 18W Plug Adapter 12V dc, 1.5A, Level VI Efficiency, 1 Output Power Adapter | fi.rsdelivers.com
SW1 | SW_Push_LED | Connectors_Molex:Molex_KK-6410-04_04x2.54mm_Straight | https://www.mouser.com/datasheet/2/140/E-Switch_06082018_PVT4_(003)-1500408.pdf | 15.77 | E-Switch | PVT4FW4SS311 | Pushbutton Switches Pushbutton Anti-vandal 19mm Illuminated Crisp Tactile Response 50mA, 24VDC, SPST Off-(On), 490gf, IP65, Wire leads 300mm, Red LED
R5 | 4.7k | Koha-Suomi:Resistor_ThroughHole_6.3x2.3mm_Spacing2.54mm | https://www.mouser.fi/datasheet/2/219/MF-MFS-RK-18760.pdf | 0.231 | KOE Speer | MF1/4DC4701F | Metal Film Resistors - Through Hole 4.7K 1% 100PPM
R6 | 110 | Koha-Suomi:Resistor_ThroughHole_6.3x2.3mm_Spacing2.54mm | https://www.mouser.fi/datasheet/2/219/MF-MFS-RK-18760.pdf | 0.231 | KOE Speer | MF1/4DC1000F | Metal Film Resistors - Through Hole 100ohm 1% 100PPM
H1 | HEADER_A_1X04 | Koha-Suomi:Pin_Header_Angled_1x04_Pitch2.54mm | https://www.mouser.com/datasheet/2/276/0022122041_PCB_HEADERS-158542.pdf | 0.639 | Molex | 22-12-2041 | Headers & Wire Housings 4 CKT R/A HEADER
H2 | HEADER_S_1X03 | Koha-Suomi:Pin_Header_Straight_1x03_Pitch2.54mm | https://www.mouser.fi/datasheet/2/276/0022102031_PCB_HEADERS-158469.pdf | 0.459 | Molex | 22-10-2031 | Headers & Wire Housings VERT PCB HDR 3P GOLD PLATING
PV4HN1 | PV4T_hex_nut | Koha-Suomi:Bad_board_tag |  |  | E-Switch | PV1PV4HEXNUT19 | Switch Hardware Hardware Hexnut for PV1, PV4 and PV Anti-Vandal Family
SOC1 | SoC | Koha-Suomi:Bad_board_tag |  | 39.3 | Raspberry Pi | Raspberry Pi 3 Model B+ | Raspberry Pi 3 Model B+ | fi.rsdelivers.com
SD1 | SD_Card | Koha-Suomi:Bad_board_tag |  | 12 | Raspberry Pi | NOOBS_32GB_Retail | SD Card preloaded with NOOBS - 32GB | fi.rsdelivers.com
U1 | Wall_PSU_5V | Koha-Suomi:Bad_board_tag |  | 6.9 | Raspberry Pi | T6716DV | Raspberry Pi, 13W Plug In Power Supply 5.1V, 2.5A, 1 Output, 2-Pin Type C - EuroPlug | fi.rsdelivers.com
RPE1 | RPi_Enclosure | Koha-Suomi:Bad_board_tag |  | 5.4 | DesignSpark | ASM-1900036-12_Bulk | Raspberry Pi 3 Enclosure, White (bulk) | fi.rsdelivers.com
US1 | USB-Stick |  |  | 17.2 | Toshiba | THN-U401S0320E4 | Toshiba 32GB TransMemory USB2.0 Metal | fi.rsdelivers.com
BCR1 | Barcode_Reader | Koha-Suomi:Bad_board_tag |  | 44.78 | WinsonChina | WGC300Usb_At
U2 | Cable_USB_TypeA_F_M |  |  | 7.9 | Roline | 11.02.8960-100 | Roline Male USB A to Female USB A USB Extension Cable, 3m | fi.rsdelivers.com
OR1 | O-Ring | Koha-Suomi:Bad_board_tag |  |  | E-Switch | PV1PV4ORING | Switch Hardware SWITCH O-RING | www.mouser.fi
STO1 | Standoff x2 | Koha-Suomi:Bad_board_tag |  | 1.14 | Adafruit | Adafruit Brass M2.5 Standoffs 16mm tall - Black Plated - Pack of 2 | ADA2337 | thepihut.com
LHI1 | LED_Holder_SML1083_fitting | Koha-Suomi:Bad_board_tag |  | 10 |  |  |  | 3D printed
LH1 | Led_Holder_SML1083 | Koha-Suomi:Bad_board_tag |  | 2.19 | ? | SML1083 | 5mm LEDKEHYS/O-RENG./LINSSI, KROMI | www.yeint.fi
H3 | HEADER_S_1X04 | Koha-Suomi:Pin_Header_Straight_1x04_Pitch2.54mm | https://www.mouser.fi/datasheet/2/276/0022032041_PCB_HEADERS-158390.pdf | 0.297 | Molex | 22-03-2041 | Headers & Wire Housings VERT PCB HDR 4P TIN PLATING
DUP1 | Dupont_Cable_4-pin | Koha-Suomi:Bad_board_tag |  | 2 |  | 2.54 pitch 4-wire cable |  |  | 20cm
LED1 | WP154A4SUREQBFZGC | Koha-Suomi:WP154A4SUREQBFZGC | https://www.mouser.fi/datasheet/2/216/WP154A4SUREQBFZGC-1173568.pdf | 1.65 | Kingbright | WP154A4SUREQBFZGC | Standard LEDs - Through Hole RGB 630/525/465nm 750/420/750mcd 60Deg
NHD1 | NHD-0420CW-AB3 | Koha-Suomi:Pin_Header_Straight_1x20_Pitch2.54mm | https://www.mouser.fi/datasheet/2/291/NHD-0420CW-AY3-587980.pdf | 25.06 | Newhaven Display | NHD-0420CW-AY3 | OLED Displays & Accessories 4x20 Yellow Slim Character OLED
H4 | HEADER_S_1X07 | Koha-Suomi:Pin_Header_Straight_1x07_Pitch2.54mm | https://www.mouser.fi/datasheet/2/276/022102074_sd-589973.pdf | 1.52 | Molex | 22-10-2074 | Headers & Wire Housings KK 100 Hdr Flat VERT 20 Au 7Ckt | www.mouser.fi
EG1 | DIY Gasket | Koha-Suomi:Bad_board_tag |  | 10 | Joensuun Kumipörssi |  | Tiivistenauha mahd. kapea
N1 | Internal enclosure |  | https://www.ikea.com/fi/fi/p/lixhult-kaappi-metalli-valkoinen-50328665/ | 12.1 | IKEA | LIXHULT | LIXHULT Kaappi, metalli, valkoinen, 25x25 cm
N2 | External enclosure |  |  | 100 | cotter.co |  | Laser cut enclosure sheets that are glued together. Price varies based on customer needs.
N3 | PCB printing and shipping |  |  | 20 | allpcb.com |  | PCB printing and shipping (constant R&D no batch orders)
 |  |  | YHTEENSÄ komponentit | 434.595
 |  |  | Pientarvikkeet | 25
 |  |  | Toimituskulut | 100
 |  |  | YHTEENSÄ TOVERI | 559.595

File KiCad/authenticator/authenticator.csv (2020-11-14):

Reference | Quantity | Value | Footprint | Datasheet | ALV0%€ | Manufacturer | Model | Title | Supplier | Length | BodyHeight
AST1 | 1 | AST-1732MR-R | Koha-Suomi:AST-1732MR-R | https://www.mouser.fi/datasheet/2/334/AST-1732MR-R-72511.pdf | 3.50 | PUI Audio | AST-1732MR-R | Speakers & Transducers SPEAKER 32OHM
BCR1 | 1 | WGC-300-USB-AT | Koha-Suomi:Bad_board_tag | https://www.winsonchina.com/wgc-300-1d-ccd-fix-mounted-barcode-scanner-p00060p1.html | 30 | Winson China | WGC-300-USB-AT
C1 | 1 | 100 uF | Koha-Suomi:UMW0G101MDD | https://www.mouser.fi/datasheet/2/293/e-umw-1219455.pdf | 0.297 | Nichicon | UMW0G101MDD | Aluminium Electrolytic Capacitors - Radial Leaded 4volts 100uF 85c 5x5 2LS
CAT1 | 1 | Cat-cable red | Koha-Suomi:Bad_board_tag | https://fi.rsdelivers.com/product/rs-pro/21991361-70/rs-pro-red-cat6-cable-s-ftp-pvc-male-rj45-male/0411481 | 6.90 | RS PRO | 411-481 | RS PRO Red Cat6 Cable S/FTP PVC Male RJ45/Male RJ45, 5m | fi.rsdelivers.com | 5m
CAT2 | 1 | Cat-cable blue | Koha-Suomi:Bad_board_tag | https://fi.rsdelivers.com/product/rs-pro/21991364-70/rs-pro-blue-cat6-cable-s-ftp-pvc-male-rj45-male/0411172 | 6.90 | RS PRO | 411-172 | RS PRO Blue Cat6 Cable S/FTP PVC Male RJ45/Male RJ45, 5m | fi.rsdelivers.com | 5m
CAT3 | 1 | Cat-cable green | Koha-Suomi:Bad_board_tag | ~ | 6.90 | RS PRO | 411-485 | RS PRO Green Cat6 Cable S/FTP PVC Male RJ45/Male RJ45, 5m | fi.rsdelivers.com | 5m
CAT4 | 1 | Cat-cable yellow | Koha-Suomi:Bad_board_tag | https://fi.rsdelivers.com/product/rs-pro/21991362-70/rs-pro-yellow-cat6-cable-s-ftp-pvc-male-rj45-male/0411491 | 6.90 | RS PRO | 557-317 | RS PRO Yellow Cat6 Cable S/FTP PVC Male RJ45/Male RJ45, 5m | fi.rsdelivers.com | 5m
D1 D2 D3 D4 D5 D6 | 6 | D | Koha-Suomi:1N4154TAP | https://www.mouser.fi/datasheet/2/427/1n4154-241332.pdf | 0.135 | Vishay Semiconductors | 1N4154TAP | Diodes - General Purpose, Power, Switching Vr/35v Io/150mA
DS1 DS2 | 2 | DS18B20+ | Koha-Suomi:TO-92_Inline_Wide | https://www.mouser.fi/datasheet/2/256/DS18B20-370043.pdf | 3.53 | Maxim Integrated | DS18B20+ | Board Mount Temperature Sensors Prgmble Resolution 1-Wire Parasite Pwr
DUP1 | 1 | Dupont_Cable_4-pin | Koha-Suomi:Bad_board_tag |  | 2 |  | 2.54 pitch 4-wire cable |  |  | 20cm
DUP2 | 1 | Dupont_Cable_3-pin | Koha-Suomi:Bad_board_tag |  | 2 |  | 2.54 pitch 3-wire cable |  |  | 20cm
EC1 EC2 EC3 | 3 | EC2-3TNU | Koha-Suomi:EC2-3TNU | https://www.mouser.fi/datasheet/2/212/KEM_R7002_EC2_EE2-1104574.pdf | 2.42 | KEMET | EC2-3TNU | Low Signal Relays - PCB 3V 2A Dbl Latching LL=3.2mm
 | 0 | DIY Gasket | Koha-Suomi:Bad_board_tag |  | 10 | Joensuun Kumipörssi |  | Tiivistenauha mahd. kapea
H1 H10 H3 | 3 | HEADER_S_1X04 | Koha-Suomi:Pin_Header_Straight_1x04_Pitch2.54mm | https://www.mouser.fi/datasheet/2/276/0022032041_PCB_HEADERS-158390.pdf | 0.297 | Molex | 22-03-2041 | Headers & Wire Housings VERT PCB HDR 4P TIN PLATING
H11 | 1 | HEADER_S_1X20 |  |  |  |  | HEADER M 1x20
H5 H6 | 2 | HEADER_A_1X07_F | Koha-Suomi:Header-1x7-F (Molex 38-00-1337) | https://www.mouser.fi/datasheet/2/276/0038001337_PCB_RECEPTACLES-159893.pdf | 1.22 | Molex | 38-00-1337 |  | Mouser
H7 | 1 | HEADER_S_1X02 | Koha-Suomi:Pin_Header_Straight_1x02_Pitch2.54mm |  | 0.339 | Molex | 22-10-2021
H2 H8 | 2 | HEADER_S_1X03 | Koha-Suomi:Pin_Header_Straight_1x03_Pitch2.54mm | https://www.mouser.fi/datasheet/2/276/0022102031_PCB_HEADERS-158469.pdf | 0.459 | Molex | 22-10-2031 | Headers & Wire Housings VERT PCB HDR 3P GOLD PLATING
H4 H9 | 2 | HEADER_S_1X07 | Koha-Suomi:Pin_Header_Straight_1x07_Pitch2.54mm | https://www.mouser.fi/datasheet/2/276/022102074_sd-589973.pdf | 1.52 | Molex | 22-10-2074 | Headers & Wire Housings KK 100 Hdr Flat VERT 20 Au 7Ckt | www.mouser.fi
HS1 HS2 | 2 | Heatsink | Koha-Suomi:Bad_board_tag | https://www.mouser.fi/datasheet/2/2/Aavid-Board-Level-Heatsinks-Catalog-2018-1507171.pdf | 5.49 | Aavid | 374624B00032G | Heat Sinks Heatsink for Metal/Ceramic BGA Packages, Black Anodized, 35x35x10mm, IC Pkg Size = 35 x 35, Tape #32
J1 J2 J5 | 3 | Screw_Terminal_01x04 | Koha-Suomi:Terminal 1x4 (Molex-398800304) | https://www.molex.com/pdm_docs/sd/398800304_sd.pdf | 1.16 | Molex | 39880-0304 | Fixed Terminal Blocks LOW PROFILE 5.08 4 A W PROFILE 5.08 4 ASY
KP1 | 1 | KeyPad | Connector_PinHeader_2.54mm:PinHeader_1x04_P2.54mm_Horizontal | https://www.alibaba.com/product-detail/12-Keys-3x4-Matrix-USB-Industrial_62481305463.html | 34 |  | D-8208J |  | Davo Electronics
LED1 | 1 | WP154A4SUREQBFZGC | Koha-Suomi:WP154A4SUREQBFZGC | https://www.mouser.fi/datasheet/2/216/WP154A4SUREQBFZGC-1173568.pdf | 1.65 | Kingbright | WP154A4SUREQBFZGC | Standard LEDs - Through Hole RGB 630/525/465nm 750/420/750mcd 60Deg
LH1 | 1 | Led_Holder_SML1083 | Koha-Suomi:Bad_board_tag |  | 2.19 | ? | SML1083 | 5mm LEDKEHYS/O-RENG./LINSSI, KROMI | www.yeint.fi
 | 0 | LED_Holder_SML1083_fitting | Koha-Suomi:Bad_board_tag |  | 10 |  |  |  | 3D printed
N1 | 1 | Internal enclosure |  | https://www.ikea.com/fi/fi/p/lixhult-kaappi-metalli-valkoinen-50328665/ | 12.10 | IKEA | LIXHULT | LIXHULT Kaappi, metalli, valkoinen, 25x25 cm
 | 0 | External enclosure |  |  | 100 | cotter.co |  | Laser cut enclosure sheets that are glued together. Price varies based on customer needs.
 | 0 | PCB printing and shipping |  |  | 20 | allpcb.com |  | PCB printing and shipping (constant R&D no batch orders)
NHD1 | 1 | NHD-0420CW-AB3 | Koha-Suomi:Pin_Header_Straight_1x20_Pitch2.54mm | https://www.mouser.fi/datasheet/2/291/NHD-0420CW-AY3-587980.pdf | 25.06 | Newhaven Display | NHD-0420CW-AY3 | OLED Displays & Accessories 4x20 Yellow Slim Character OLED
R1 | 1 | 110 | Koha-Suomi:Resistor_ThroughHole_6.3x2.3mm_Spacing2.54mm | https://www.mouser.fi/datasheet/2/219/MF-MFS-RK-18760.pdf | 0.231 | KOA Speer | MF1/4DC1000F | Metal Film Resistors - Through Hole 100ohm 1% 100PPM
R2 R3 | 2 | 220 | Koha-Suomi:Resistor_ThroughHole_6.3x2.3mm_Spacing2.54mm | https://www.mouser.fi/datasheet/2/219/MF-MFS-RK-18760.pdf | 0.191 | KOA Speer | MF1/4CCT52R2200F | Metal Film Resistors - Through Hole 1/4 WATT 220 OHM 1%
R4 | 1 | 4.7k | Koha-Suomi:Resistor_ThroughHole_6.3x2.3mm_Spacing2.54mm | https://www.mouser.fi/datasheet/2/219/MF-MFS-RK-18760.pdf | 0.231 | KOE Speer | MF1/4DC4701F | Metal Film Resistors - Through Hole 4.7K 1% 100PPM
R5 | 1 | 50 | Koha-Suomi:Resistor_ThroughHole_6.3x2.3mm_Spacing2.54mm | https://www.mouser.fi/datasheet/2/219/MOS-16613.pdf | 0.101 | KOE Speer | MOS1CT528R510J | Metal Oxide Resistors 51 ohm 5% 1W
RJ1 RJ2 RJ3 RJ4 | 4 | RJ45_2xPort-Koha-Suomi | Koha-Suomi:RJ45 dual port - WE-15016137621 | https://katalog.we-online.com/em/datasheet/615016137621.pdf | 3.51 | Wurth Elektronik | WE-15016137621 | Modular Connectors / Ethernet Connectors WR-MJ Feml Shielded 8P8C Hztl Dual Port
RPE1 | 1 | RPi_Enclosure | Koha-Suomi:Bad_board_tag |  | 5.40 | DesignSpark | ASM-1900036-12_Bulk | Raspberry Pi 3 Enclosure, White (bulk) | fi.rsdelivers.com
RPi1 | 1 | RPi_GPIO | Koha-Suomi:PI_GPIO_Header_F_2x20 | https://www.mouser.fi/datasheet/2/527/esw_th-1369991.pdf | 6.00 | Samtec | ESW-120-24-L-D | Samtec, ESQ 2.54mm Pitch 40 Way 2 Row Vertical PCB Socket, Through Hole, Solder Termination | Mouser |  | 13.59mm
SD1 | 1 | SD_Card | Koha-Suomi:Bad_board_tag |  | 12 | Raspberry Pi | NOOBS_32GB_Retail | SD Card preloaded with NOOBS - 32GB | fi.rsdelivers.com
SOC1 | 1 | SoC | Koha-Suomi:Bad_board_tag |  | 39.30 | Raspberry Pi | Raspberry Pi 3 Model B+ | Raspberry Pi 3 Model B+ | fi.rsdelivers.com
STO1 | 1 | Standoff x2 | Koha-Suomi:Bad_board_tag |  | 1.14 | Adafruit | Adafruit Brass M2.5 Standoffs 16mm tall - Black Plated - Pack of 2 | ADA2337 | thepihut.com
T2 | 1 | Screw_Terminal_01x02 | Koha-Suomi:Screw_Terminal_01x02 (Molex) | https://www.mouser.fi/datasheet/2/276/0398800302_TERMINAL_BLOCKS-167600.pdf | 0.648 | Molex | 39880-0302 | Fixed Terminal Blocks 2 CKT TERM. BLOCK 5.08mm
TH1 | 1 | Thermistor_PTC | Koha-Suomi:1N4154TAP | https://docs-emea.rs-online.com/webdocs/0f72/0900766b80f72deb.pdf | 15.30 | DBK Enclosures | HPG-2/08-75X35-12-30 | Enclosure Heating Element, 18W, 80°C, 12 → 30 V ac/dc | fi.rsdelivers.com
U1 | 1 | Wall_PSU_5V | Koha-Suomi:Bad_board_tag |  | 6.90 | Raspberry Pi | T6716DV | Raspberry Pi, 13W Plug In Power Supply 5.1V, 2.5A, 1 Output, 2-Pin Type C - EuroPlug | fi.rsdelivers.com
U2 | 1 | Cable_USB_TypeA_F_M |  |  | 7.90 | Roline | 11.02.8960-100 | Roline Male USB A to Female USB A USB Extension Cable, 3m | fi.rsdelivers.com
US1 | 1 | USB-Stick |  |  | 17.20 | Toshiba | THN-U401S0320E4 | Toshiba 32GB TransMemory USB2.0 Metal | fi.rsdelivers.com
V1 | 1 | +12V | Koha-Suomi:1N4154TAP | ~ | 9.10 | RS PRO | 175-3316 | RS PRO, 18W Plug Adapter 12V dc, 1.5A, Level VI Efficiency, 1 Output Power Adapter | fi.rsdelivers.com
ZM1 | 1 | ZM10E10B01 | Koha-Suomi:Bad_board_tag | https://www.mouser.fi/datasheet/2/187/honeywell-sensing-micro-switch-ZM-ZM1-basic-produc-1266371.pdf | 2.81 | Honeywell | ZM10E10C01

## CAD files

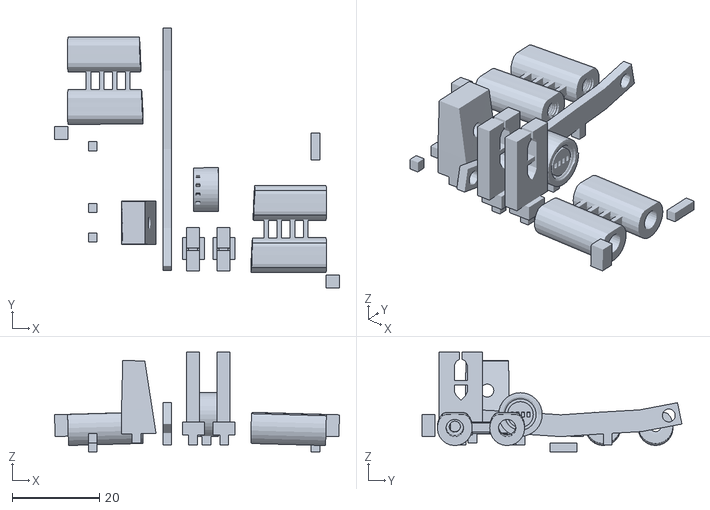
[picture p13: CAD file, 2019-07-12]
Blender/Toveri3D_printable_minimum.stl
65.3 x 59.5 x 22.8

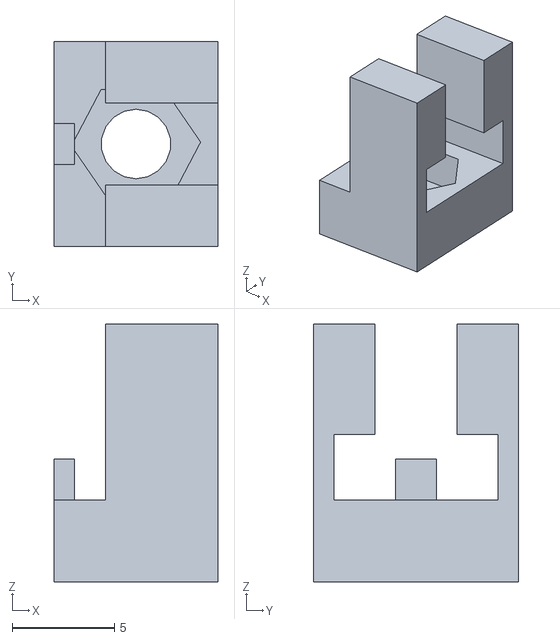
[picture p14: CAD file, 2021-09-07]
FreeCAD/LidNutHolder.obj
8.00 x 10.0 x 12.6

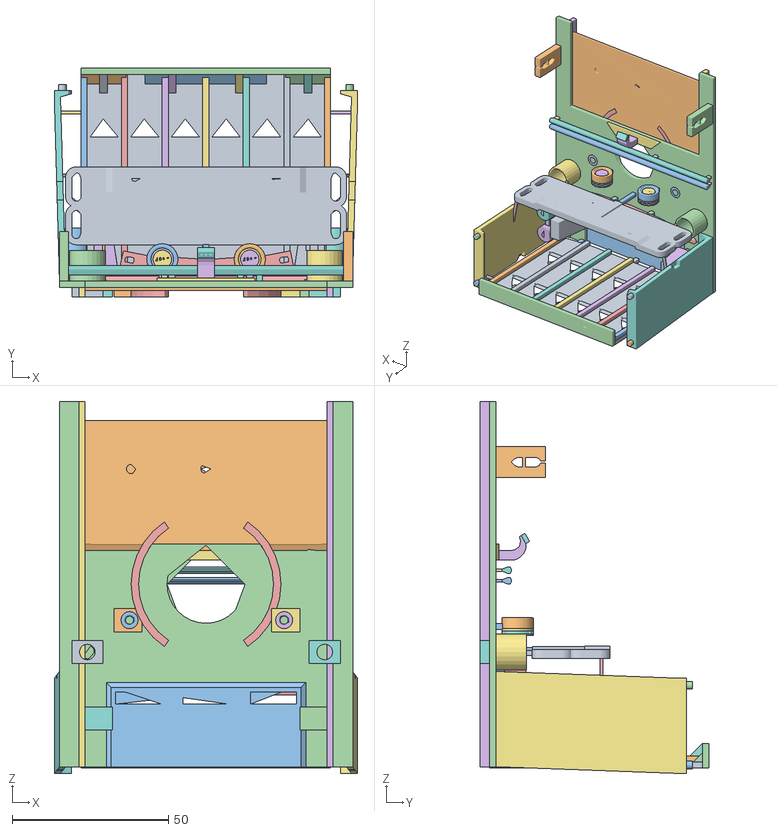
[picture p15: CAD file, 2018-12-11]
Blender/Toveri3D_printable_with_protplate.obj
97.2 x 73.2 x 119.1
card_reader_angler.001_Circle.000
Cube.020_Cube.008
Cube.019_Cube.007
Cube.018_Cube.002
Cube.017_Cube.001
Circle.011_Circle.024
Circle.010_Circle.023
Circle.009_Circle.021
Circle.008_Circle.020
Plane.001_Plane.012
Cube.011_Cube.124
Cube.061_Cube.123
Cube.059_Cube.122
Cube.054_Cube.117
Cube.038_Cube.116
Cube.037_Cube.115
Cube.036_Cube.114
Cube.026_Cube.112
Plane.002_Plane.009
Circle.007_Circle.019
Circle.006_Circle.018
Circle.005_Circle.017
Circle.000_Circle.016
Cube.025_Cube.111
Cube.024_Cube.110
Cube.023_Cube.109
Cube.022_Cube.107
Cube.016_Cube.101
Cube.015_Cube.100
Cube.014_Cube.099
Cube.005_Cube.098
Cube.004_Cube.097
Cube.003_Cube.096
Cube.002_Cube.095
Cube.001_Cube.094
Cube_Cube.093
Tmp2.003_Tmp2.002
DS18B20_holder_footing_Cube.091
DS18B20_baseplate_Cube.090
DS18B20_holder_Circle.022
Cube.066_Cube.030
Cube.051_Cube.084
Cube.050_Cube.061
Cube.032_Cube.038
Cube.031_Cube.037
Cube.030_Cube.036
Cube.029_Cube.035
Cube.028_Cube.034
Cube.027_Cube.032
heater_mount.002_Cube.031
Cube.013_Cube.029
heater_mount_Cube.028
Cylinder.029_Cylinder.008
Cube.010_Cube.013
Tmp2.006_Tmp2.007
Tmp2.005_Tmp2.006
Tmp2.004_Tmp2.005
Tmp.004
Tmp2.002_Tmp2.003
Cube.008_Cube.006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

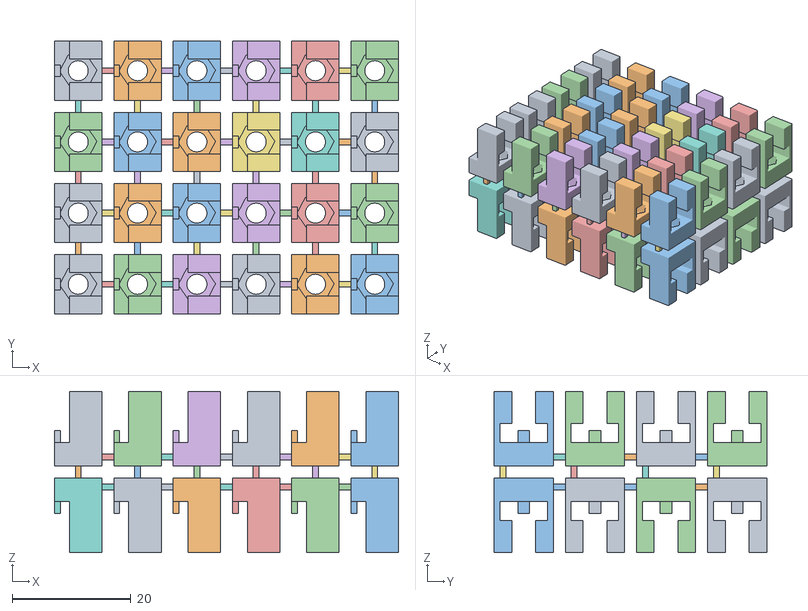
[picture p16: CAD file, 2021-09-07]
FreeCAD/LidNutHolder-panel.obj
58.0 x 46.0 x 27.2
Cube.002_Cube.001
Cube.002_Cube.002
Cube.002_Cube.004
Cube.002_Cube.006
Cube.002_Cube.005
Cube.002_Cube.011
Cube.002_Cube.010
Cube.002_Cube.009
Cube.002_Cube.008
Cube.002_Cube.007
Cube.002_Cube.012
Cube.002_Cube.013
Cube.002_Cube.014
Cube.002_Cube.015
Cube.002_Cube.016
Cube.002_Cube.017
Cube.002_Cube.018
Cube.002_Cube.029
Cube.002_Cube.028
Cube.002_Cube.027
Cube.002_Cube.026
Cube.002_Cube.025
Cube.002_Cube.024
Cube.002_Cube.023
Cube.002_Cube.022
Cube.002_Cube.021
Cube.002_Cube.020
Cube.002_Cube.019
Cube.002_Cube.057
Cube.002_Cube.056
Cube.002_Cube.055
Cube.002_Cube.054
Cube.002_Cube.053
Cube.002_Cube.052
Cube.002_Cube.051
Cube.002_Cube.050
Cube.002_Cube.049
Cube.002_Cube.048
Cube.002_Cube.047
Cube.002_Cube.046
Cube.002_Cube.045
Cube.002_Cube.044
Cube.002_Cube.043
Cube.002_Cube.042
Cube.002_Cube.041
Cube.002_Cube.040
Cube.002_Cube.039
Cube.002_Cube.038
Cube.002_Cube.037
Cube.002_Cube.036
Cube.002_Cube.035
Cube.002_Cube.034
Cube.002_Cube.033
Cube.002_Cube.032
Cube.002_Cube.031
Cube.002_Cube.030
Cube.002_Cube.085
Cube.002_Cube.084
Cube.002_Cube.083
Cube.002_Cube.082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

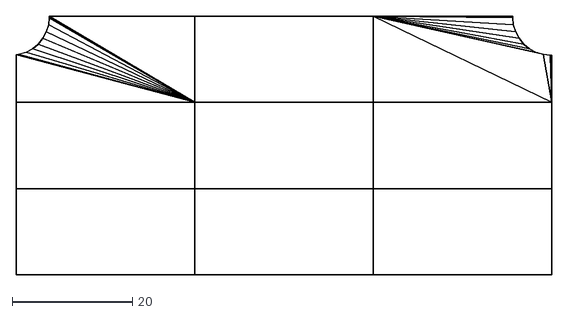
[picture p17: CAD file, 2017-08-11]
Blender/screen protector.dxf
89.0 x 43.0

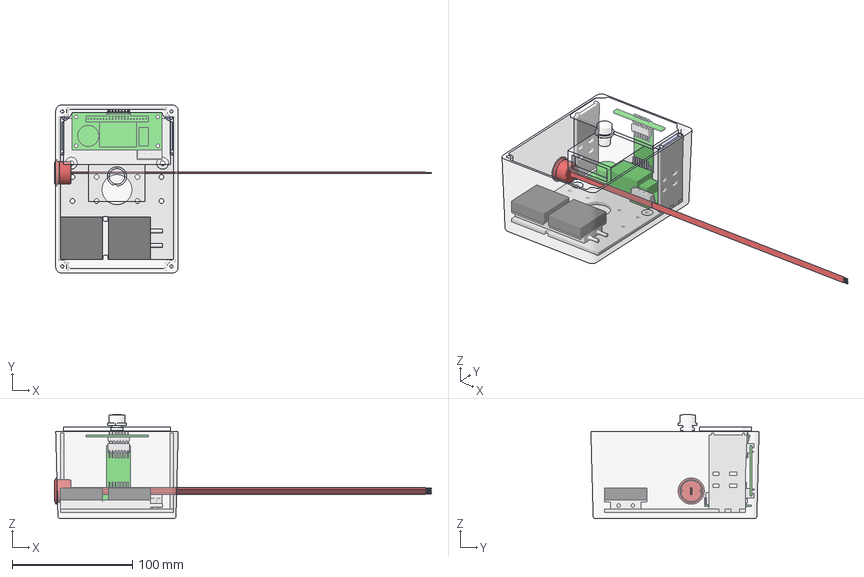
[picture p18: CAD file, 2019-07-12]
FreeCAD/Toveri.FCStd
313.8 x 140.0 x 86.8 mm
OLED window
Base plate
OLED stand L
OLED stand R
Reader mount
Base plate anchor L
Base plate anchor R
PCB Main
Molex - 22-10-2074 001
PCB OLED stand
Molex - 38-00-1337 001
Molex - 38-00-1337 002
PCB isolation mat
Molex - 398800304
NHD-0420
NHD-0420 config PCB
Molex - 22-10-2074 002
_550K
Aavid - 374624B00032G 001
Aavid - 374624B00032G 002
DBK - HPG-2/08-75X35-12-30
Winston - WGC-300-USB-AT
PVT4FW4SS311
rgb-led

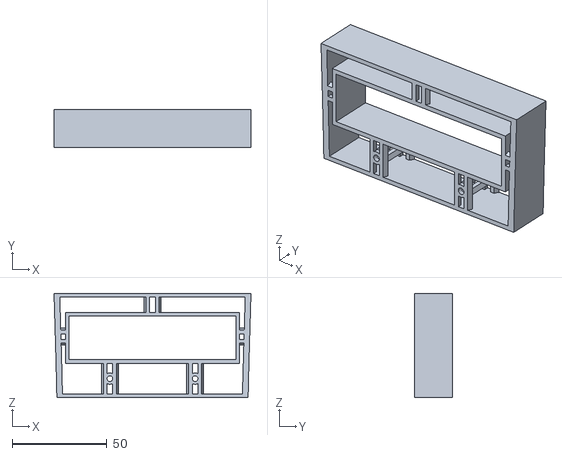
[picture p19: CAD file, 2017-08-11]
Blender/libarycard_guide_heightener2.stl
104.0 x 20.0 x 55.0

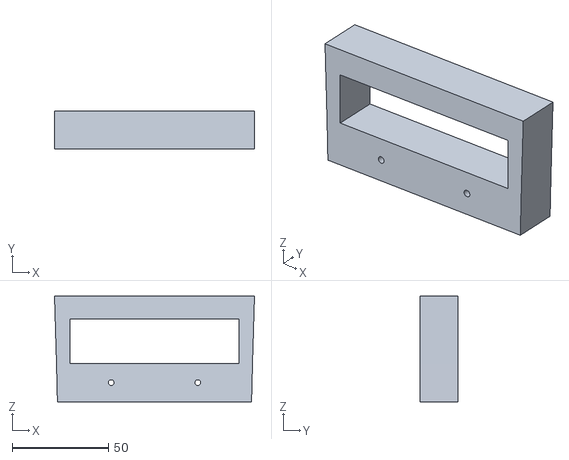
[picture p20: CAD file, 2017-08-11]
Blender/librarycard_guide_extension.dxf
104.0 x 20.0 x 55.0

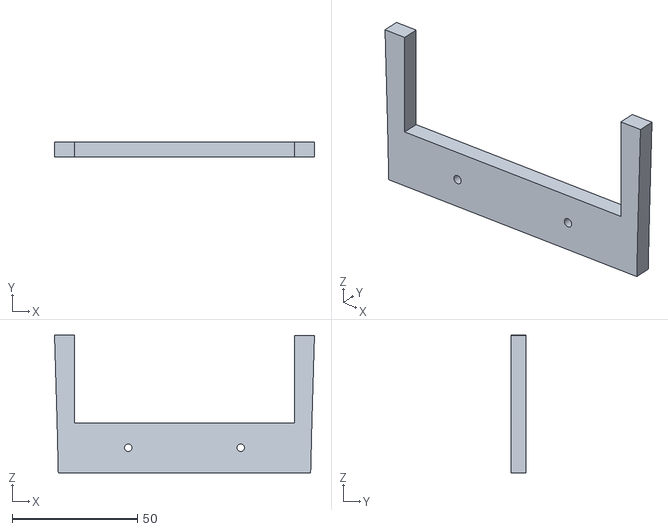
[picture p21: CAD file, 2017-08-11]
Blender/librarycard_guide_input.dxf
104.0 x 6.00 x 55.0

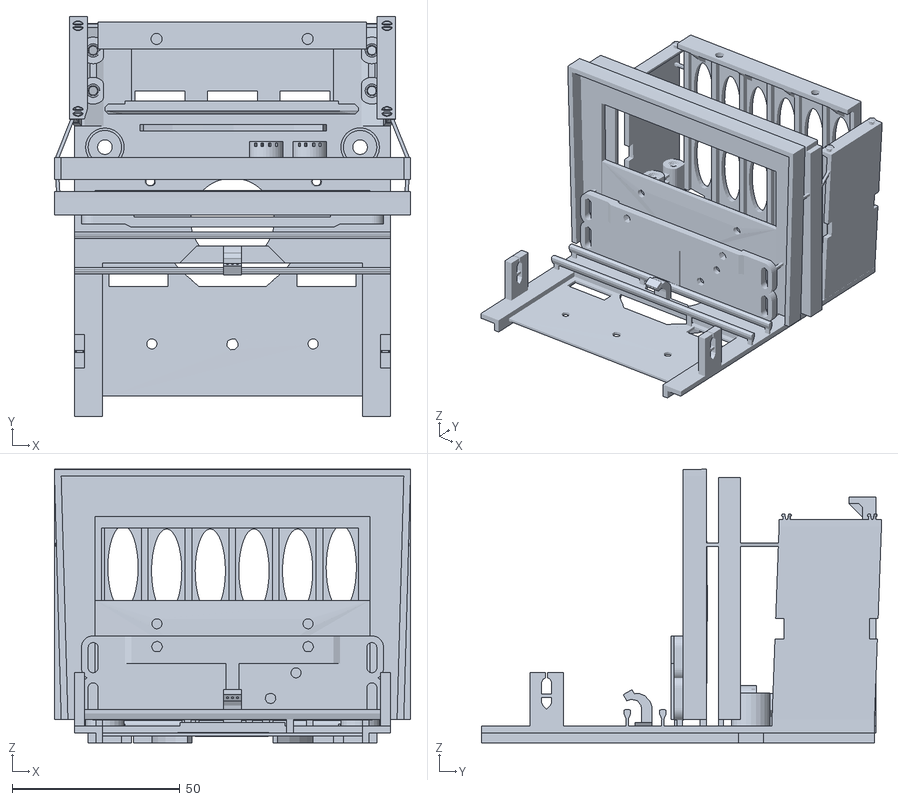
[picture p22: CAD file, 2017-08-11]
Blender/Toveri3D_printable.stl
106.0 x 119.1 x 81.5

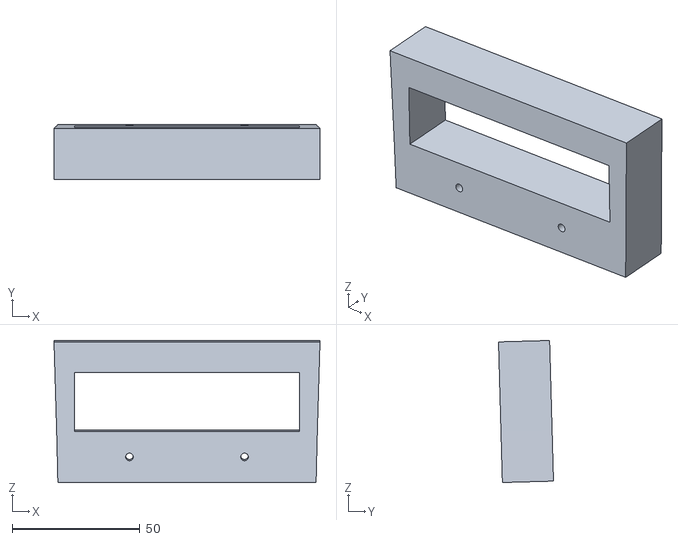
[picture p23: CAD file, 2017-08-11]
Blender/libarycard_guide_heightener.stl
104.0 x 21.5 x 55.5

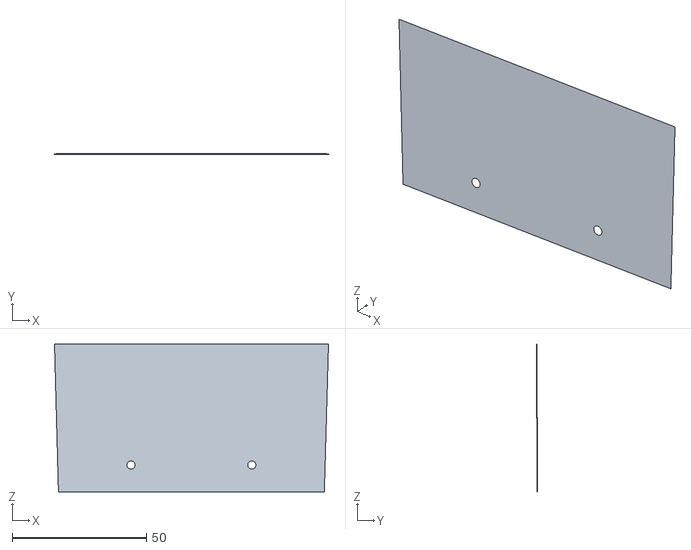
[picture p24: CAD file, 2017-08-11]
Blender/librarycard_guide_bottom.dxf
102.0 x 0.0239 x 55.0

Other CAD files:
Blender/Lainuri.blend
Blender/Lainuri_lasers.blend
Blender/Toveri3D_printable.blend
Blender/Toveri3D_printable_minimum.blend
Blender/Toveri3D_printable_minimum.obj
Blender/Toveri3D_printable_with_guides.blend
Blender/Toveri3D_printable_with_protplate.blend
Blender/enclosure_3d_printable.blend
Blender/enclosure_3d_printable_print-layout.blend
Blender/interior_enclosure.blend
Blender/screw profiles.blend

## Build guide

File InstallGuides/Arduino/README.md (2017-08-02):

# Arduino test suite

Used to verify different parts of Toveri work as expected. Use this suite to close out malfunctioning parts.

## Installation

1. Install Arduino IDE
   http://www.arduino.org/downloads

2. Copy libraries to Arduino IDE libraries directory
   Change paths as needed.

    cp -r libraries/* ~/arduino-1.8.3/libraries/

3. Open Arduino IDE

4. Open ToveriTestBed.ino from Arduino IDE

5. Wire Arduino prototyping breadboard with Toveri components
   Use the KiCad schematics or try to follow these pictures.
   A readily assembled protoboard should be lying somewhere around.

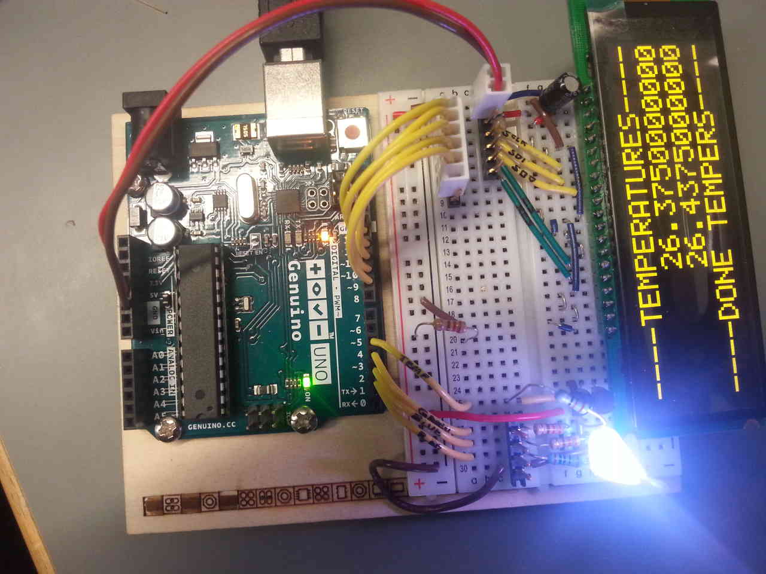
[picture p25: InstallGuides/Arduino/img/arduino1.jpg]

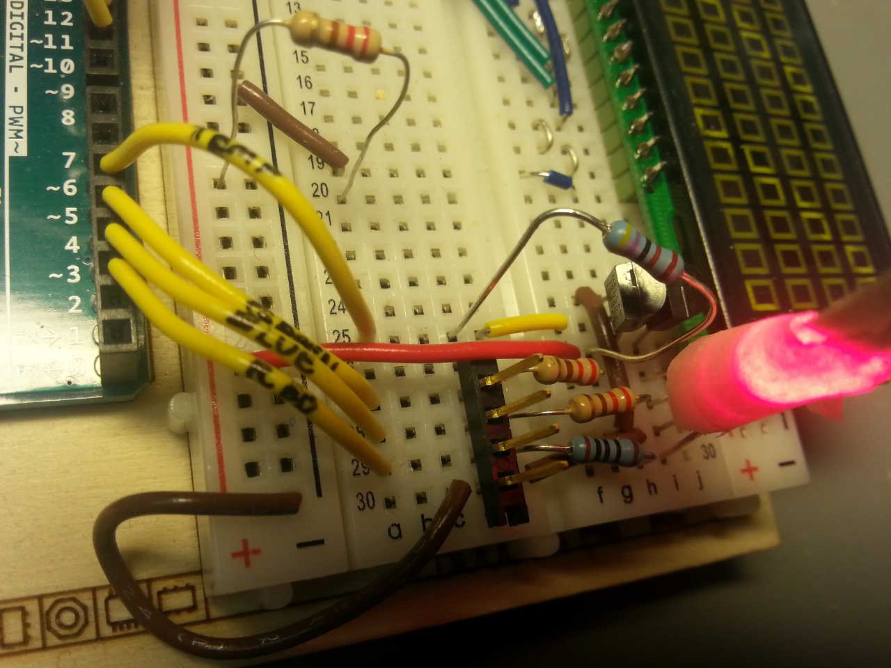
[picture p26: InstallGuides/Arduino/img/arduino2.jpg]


6. Upload the program to Arduino.

7. Test each individual component.
   Simply replace working components with fresh components from the storage to test if they work properly.
   Test also the cables you make using this testbed.
   Arduino test bed is wired in such a way that it is compatible with the Toveri PCB.
   You can test the PCB by wiring cables from Arduino testbed to the PCB.

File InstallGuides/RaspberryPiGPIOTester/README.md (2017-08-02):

# Raspberry Pi GPIO test utility

Use this to verify that you have wiringPi and HiPi properly installed.
Raspberry hardware works as expected.

This should be done whenever an new Raspberry Pi is being deployed.

There propably are better and smarter tools for this, if so, pre-emptively order them beforehand.
This is what I made from the stuff I had in the timeframe I had.

## Dependencies

- http://wiringpi.com/download-and-install/
  You should do the git install for the latest version

- cpanm HiPi
  http://raspberrypi.znix.com/hipidocs/
  Note! as of writing, do not install using hipi-install as it installs a old and incompatible version.

## Building the hardware

You should have one of these lying around, but if you need to make one, here are example pictures of it.
Basically it is an array of components that gives some feedback which is easy to trace back to the individual
GPIO pin.

In this case I chose LEDs, which blink nicely and are easy to spot if one of these leds fails to blink.

See the images for inspiration:
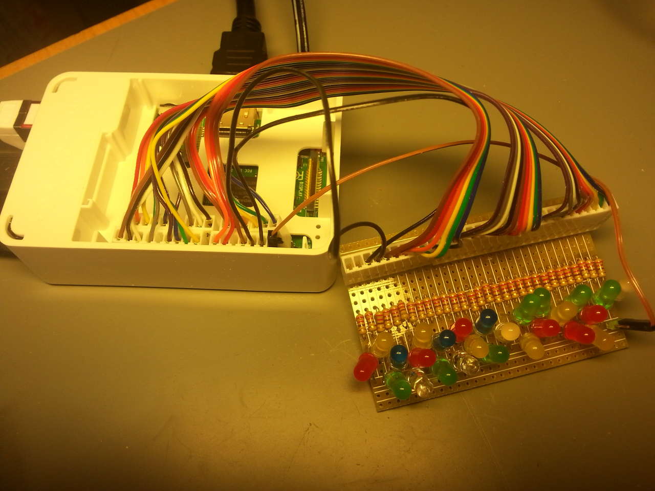
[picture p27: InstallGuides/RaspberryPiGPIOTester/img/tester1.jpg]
test1

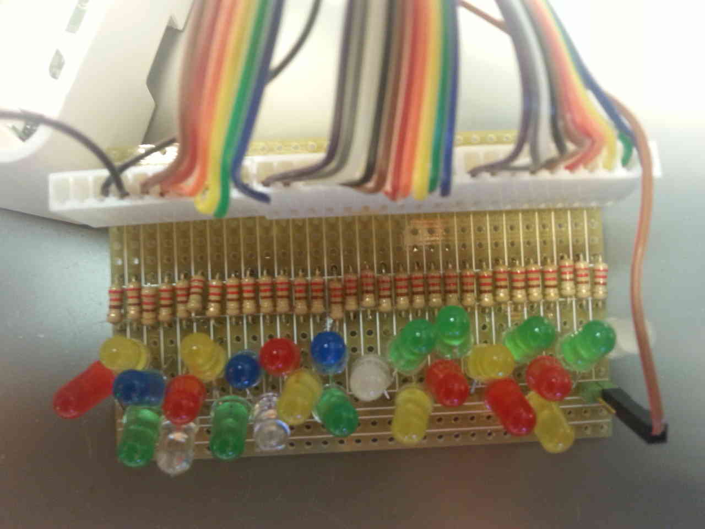
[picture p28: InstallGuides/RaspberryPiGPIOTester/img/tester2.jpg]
test2


See

    0-pins-to-test.cfg

for the physical Raspberry Pi pins you need to connect to the test board. Connect them in the order listed
in 0-pins-to-test.cfg

## Usage

Read "IN THIS FILE" and execute script:

    ./testGPIOPins.sh

## When led doesn't blink

It is possible for a LED to malfunction or the wiring/soldering to break. If you detect a possibly broken
GPIO pin, test the pin/cable/connectors using an external 3V3 power source if it actually works, or if the
problem is with the GPIO pin.

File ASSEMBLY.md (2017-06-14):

###IN THIS DOCUMENT
We define how to assemble the Toveri.
###OVERVIEW OF THE ASSEMBLY
The assembly is divided into the following steps and documents supporting the steps:

**Table of Contents**

[TOC]

## 1. Ordering all the needed components, devices and tools.

###Used suppliers

These suppliers should have access to the desired components:

- www.mouser.fi
- www.yeint.fi
- fi.rsdelivers.com      (Raspberry Pis)
- www.signalpartners.fi  (GFS4400)
- www.wurthelektronik.fi (ohutlevykiinnikkeet)

###Bill of materials

Supplier | Mfr. # | Description | Quantity
---------|--------|---------------|------------
-PCB- | | |
Mouser | UMW0G101MDD | Aluminium Electrolytic Capacitors - Leaded 4volts 100uF 85c 5x5 2LS | 1
Mouser | MF1/4DC4701F | Metal Film Resistors - Through Hole 4.7K 1% 100PPM | 1
Mouser | MF1/4DC1000F | Metal Film Resistors - Through Hole 100ohm 1% 100PPM | 3
Mouser | MF1/4CCT52R2200F | Metal Film Resistors - Through Hole 1/4 WATT 220 OHM 1% | 3
Mouser | EC2-3NU | Low Signal Relays - PCB 3V 10uA Relay Signal 2formC | 1
Mouser | EC2-3TNU | Low Signal Relays - PCB 3V 10uA Relay Signal 2formC | 1
Mouser | TP224003-3 | Speakers & Transducers Piezo Transducer | 1
Mouser | DS18B20+ | Board Mount Temperature Sensors Prgmble Resolution 1-Wire Parasite Pwr | 1
Mouser | C3200-6136A | Thermoelectric Modules FLEX HEATERS | 1
Mouser | SB400 | PCBs & Breadboards 400 TIE POINT SLDR PC BDBOARD | 1
Mouser | 1550KBK | Enclosures, Boxes & Cases Diecast Aluminum Box 5.51x2.9x4.02" Black | 1
Mouser | 1550KSGASKET | Enclosures, Boxes & Cases IP68 GasketKit/Pack2 For use with 1550K | 0.5
yeint | 1551GFLGY | ABS-MUOVIK.50x35x20mm HARMAA IP54 | 1
Mouser | 1N4154TAP | Diodes - General Purpose, Power, Switching Vr/35v Io/150mA | 3
Mouser | WP154A4SUREQBFZGC | Standard LEDs - Through Hole RGB 630/525/465nm 750/420/750mcd 60Deg | 1
Mouser | NHD-0420CW-AB3 | OLED Displays & Accessories 4x20 Blue Slim Character OLED | 1
yeint  | SML1083 | 5mm LEDKEHYS/O-RENG./LINSSI, KROMI | 1
yeint | 5-826629-0 | 1X50NAP SUORA, KULTA | 1

-DEVICES- | | |
RS | 896-8660 | Raspberry Pi 3 Model B | 1
RS | 909-8138 | Official Raspberry Pi 3 B Development Board Case, Black, Grey | 1
RS | 909-8135 | Official Pi 3 Power Supply Black | 1
RS | 917-6317 | Sandisk Micro SD Card NOOBS Raspberry Pi | 1
Signalpartners | GFS4470 | Datalogic Gryphon GFS4400 USB | 1
yeint | MW 3IP25GS | HAKKURITEHOLÄHDE 100-240V/3-12V/27W | 1

-CABLING- | | |
yeint | 135.2802.326 | 26-NAP. AWG28 7/0 VÄRIKOOD. 30.5m | 3m
08-50-0114 | Headers & Wire Housings CRIMP TERM 22-30 TIN | 100
Mouser | 22-01-2107 | Headers & Wire Housings HSG 10P W/LKG RAMP | 2
Mouser | 22-01-3067 | Headers & Wire Housings HSG 6P W/RAMP/RIBS | 2
Mouser | 22-01-3057 | Headers & Wire Housings HSG 5P W/RAMP/RIBS | 5
Mouser | 22-01-3047 | Headers & Wire Housings HSG 4P W/RAMP/RIBS | 2
Mouser | 22-01-2037 | Headers & Wire Housings HSG 3P WITH LKG RAMP | 2
Mouser | 22-01-3027 | Headers & Wire Housings HSG 2P W/RAMP/RIBS | 5
Mouser | 22-05-2081 | Headers & Wire Housings R/A PCB HDR 8P TIN PLATING | 2
Mouser | 22-05-2111 | Headers & Wire Housings R/A PCB HDR 11P TIN PLATING | 1
Mouser | 22-03-2051 | Headers & Wire Housings VERT PCB HDR 5P TIN PLATING | 2
Mouser | 22-03-2031 | Headers & Wire Housings VERT PCB HDR 3P TIN PLATING | 2
yeint | USB2-AAMF180M | USB2.0 JATKOKAAPELI 1.8m | 1
yeint | CAT6-300SSTP-VA | CAT6 kaapeli sftp valkoinen 3m | 1
yeint | 810-4605YE | DC Naarasliitin 5.5x2.1mm ruuvil. | 1

-TOOLS- | | |
-cables- | | |
Mouser | 76650-0009 | Headers & Wire Housings .100KK CONNECTOR KIT PREM CRIMPTOOL 184PC  | 1
Mouser | 8PK-3001D | Wire peelers 0,2-0,8mm2 AWG 20-30 | 1
Rautakauppa | | 30mm saw drill for making a hole in the enclosure | 1
Rautakauppa | | 25mm diameter pipe to pass through the exterior wall and protect cabling | 50cm
-soldering-  | | |
yeint | SS-257B | JUOTINASEMA DIGIT 75W ESD USB | 1
yeint | 5SI-216N-0,8D | VARATERÄ 0,8mm TALTTA | 2
yeint | MINI FLUXER 500-6B | FLUKSIKYNÄ AKTIV 10ML LF NO-CLEAN | 1
yeint | ECO TSC263-115-0.3-2 | SAC-JUOTOSTINA 250G 0.3 KS115 1C | 1
yeint | STAND20 | JUOTINTELINE YLEISKÄYTTÖÖN | 1
yeint | 608-391A | PIIRILEVYNPIDIN, APUKÄSI, LUUPPI | 1
yeint | 52242099 | PUHDISTUSSIENI 2-kerros 5KPL/PKT | 1
yeint | WDC-V2 | KUIVAPUHDISTINVILLA RST, WDC2, 2KPL | 1
yeint | KONTAKT IPA | ISOPROPANOLIPUHDISTUSAINE 200 ml | 1
yeint | AA1.5 |	TINAIMUNAUHA 1.5mm/1.5m KELTAINEN | 1
-wall mounting- | | |
Wurth | | Niittimutteripihdit | 1

-ACCESSORIES- | | |
Rautakauppa | | M3 bolts 10mm and accessories | 10
Rautakauppa | | M3 bolts 25mm and accessories | 7
Rautakauppa | | Concrete anchor and screw for a 4mm enclosure hole  | 2
Rautakauppa | | Metal plate (depth 2mm) anchor and screws for 4mm enclosure hole | 2
Wurth | | Niittimutterit M3 | 2
Rautakauppa | | Rubber insulation rim for a 30mm hole and 25mm pipe | 1
Rautakauppa | | Rubber insulation rim for 5mm hole | 2
Rautakauppa | | Silicone insulation sheet | 48 x 76 x 1mm
Rautakauppa | | Silicone insulation sheet | 48 x 15 x 1mm

## 2. Soldering the PCB
Open KiCad/authenticator/authenticator.pro with KiCad and navigate to the electronic schema. Solder this to the general purpose PCB

## 3. Manufacturing the Electronic enclosure and connection rails
Open Blender/enclosure.blend for the layered model of the enclosure, connection rails and electronic components.
Easiest way is to order 3D-prints of the internal plastic pieces from Shapeways.com.
You can also extract the measurements and send it to a CNC workshop for production,
or you can relatively easily make the connection railings and back plate by hand. Polycarbonate is an easy-to-mold material using a hot air gun and can be acquired rather cheaply from for ex http://www.joensuunkumiporssi.fi/etusivu/

## 4. Making the cabling
Find nice instructables in youtube on how to make Molex headers. Use search words like "Assembling a Molex Connector"
See the KiCad/authenticator/authenticator.pro for the used headers.

## 5. Assembling all the components
See the Blender model for where everything belongs.
TODO an assembly video.

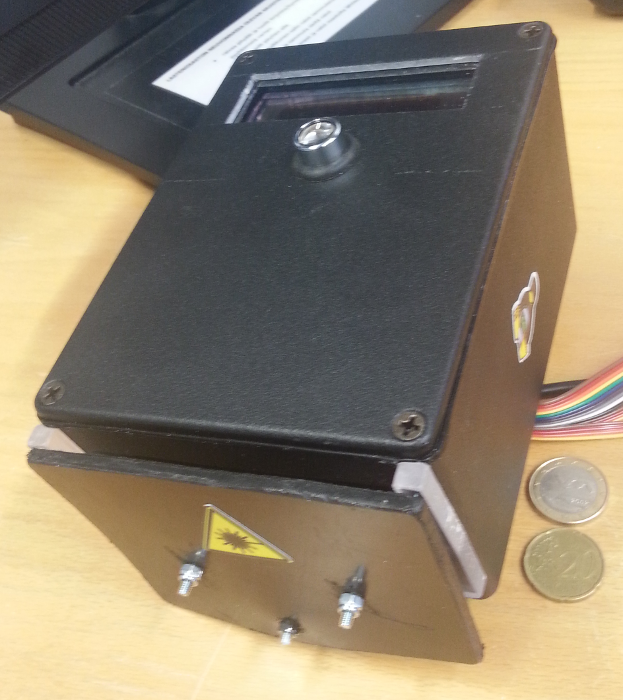
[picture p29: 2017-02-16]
Pictures/Assembled/toveri_iso2.png

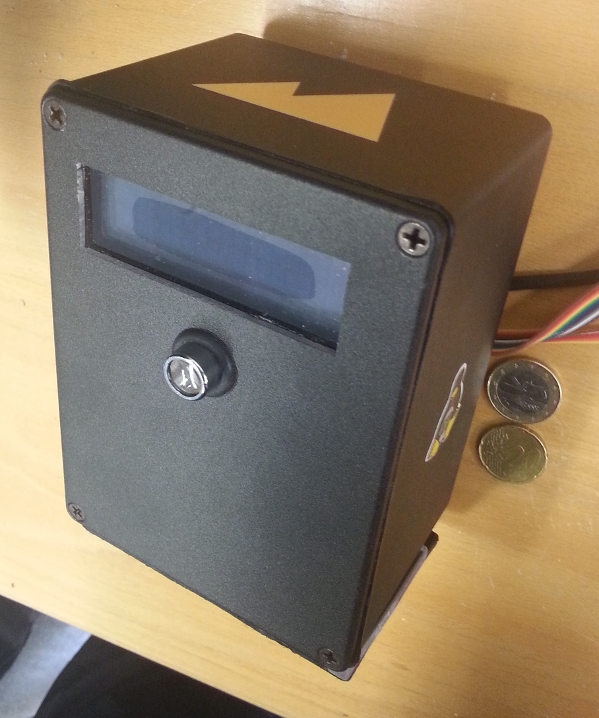
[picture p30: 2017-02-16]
Pictures/Assembled/toveri_iso.png

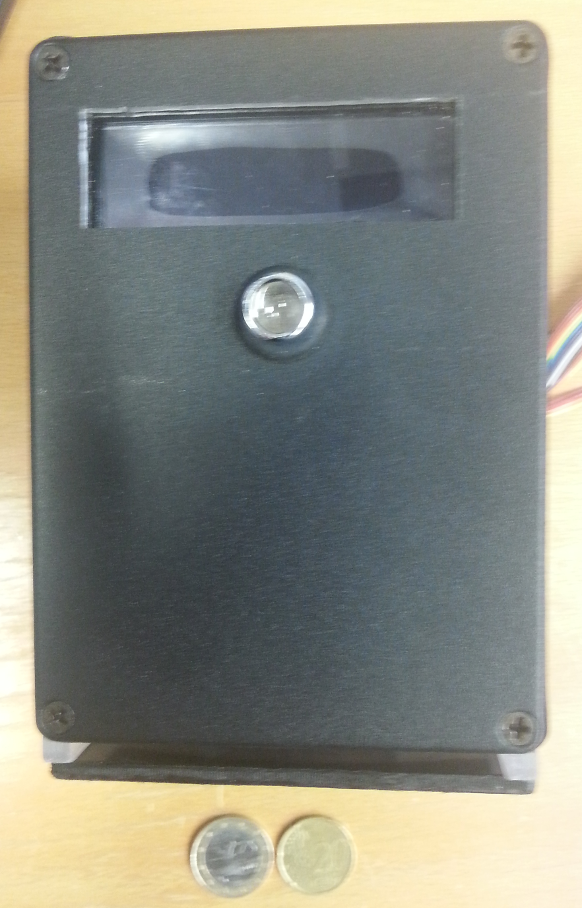
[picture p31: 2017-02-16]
Pictures/Assembled/toveri_front.png

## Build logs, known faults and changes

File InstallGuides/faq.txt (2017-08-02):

##   IN THIS FILE   ##
#
# Try to answer some common problems when assembling the Toveri
#

When a component (OLED-display mainly) fails to work, the problem can be hard to find.

-The problem can be in the component.
  * Component is broken

-In the way the headers are soldered.
  * You broke the component

-Cabling is broken.
  * Molex-connectors are poorly attached
  * A pre-assembled dupont-cable is missing the conduction core (trust me this can happen!)
  * Test cables for capacitance, cables can break if twisted too much. Test the connections for capacitance.

-Headers do not contact properly to the PCB
  * Check soldering!

-Cabling or PCB is wired wrong.
  * OLED starts to heat quickly if +3.3V is somewhere else than where it should be.
  * This will brick the device
  * Check correct wiring from the KiCad schematic

-Raspberry Pi has a faulty GPIO-pin or the software version is buggy
  * Use the Raspberry Pi GPIO tester (RaspberryPiGPIOTester) to test that GPIO pins and software work as expected.

-Raspberry Pi cannot properly drive the SPI-pins
  * Run emb-oled -project's clib/test as bare-metal test suite.
  * Use the Arduino test bed (Arduino-dir) to verify the component is not broken.

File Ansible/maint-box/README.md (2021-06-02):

# maint-box

A simple Raspberry box to be taken with on an installation trip.

A remote connection to the box should be prepared from the central controller.
Then the box has all the tools to locally modify the Toveri SD-card/USB-drive.

- reconfigure network
- reset root password
- etc...

Also the box operates as a DHCP server, so it can be plugged directly into another Raspberry Pi with DHCP and ssh'd over.

# DHCP server

Uses

    isc-dhcp-server

Script based on https://blog.monotok.org/setup-raspberry-pi-dhcp-server/

Check DHCP leases with

    cat /var/lib/dhcp/dhcpd.leases

# DHCP server instructions summary

$ sudo apt-get install isc-dhcp-server

$ sudo nano /etc/dhcpcd.conf
```
# Example static IP configuration:
interface eth0
static ip_address=192.168.0.10/24
```

$ sudo nano /etc/resolv.conf
```
domain lan
```

$ sudo nano /etc/default/isc-dhcp-server
```
INTERFACES="eth0"
```

$ sudo nano /etc/dhcp/dhcpd.conf
```
# option definitions common to all supported networks...
option domain-name "lan";

# If this DHCP server is the official DHCP server for the local
# network, the authoritative directive should be un-commented.
authoritative;

# This is a very basic subnet declaration.
subnet 192.168.0.0 netmask 255.255.255.224 {
  range 192.168.0.11 192.168.0.20;
}
```

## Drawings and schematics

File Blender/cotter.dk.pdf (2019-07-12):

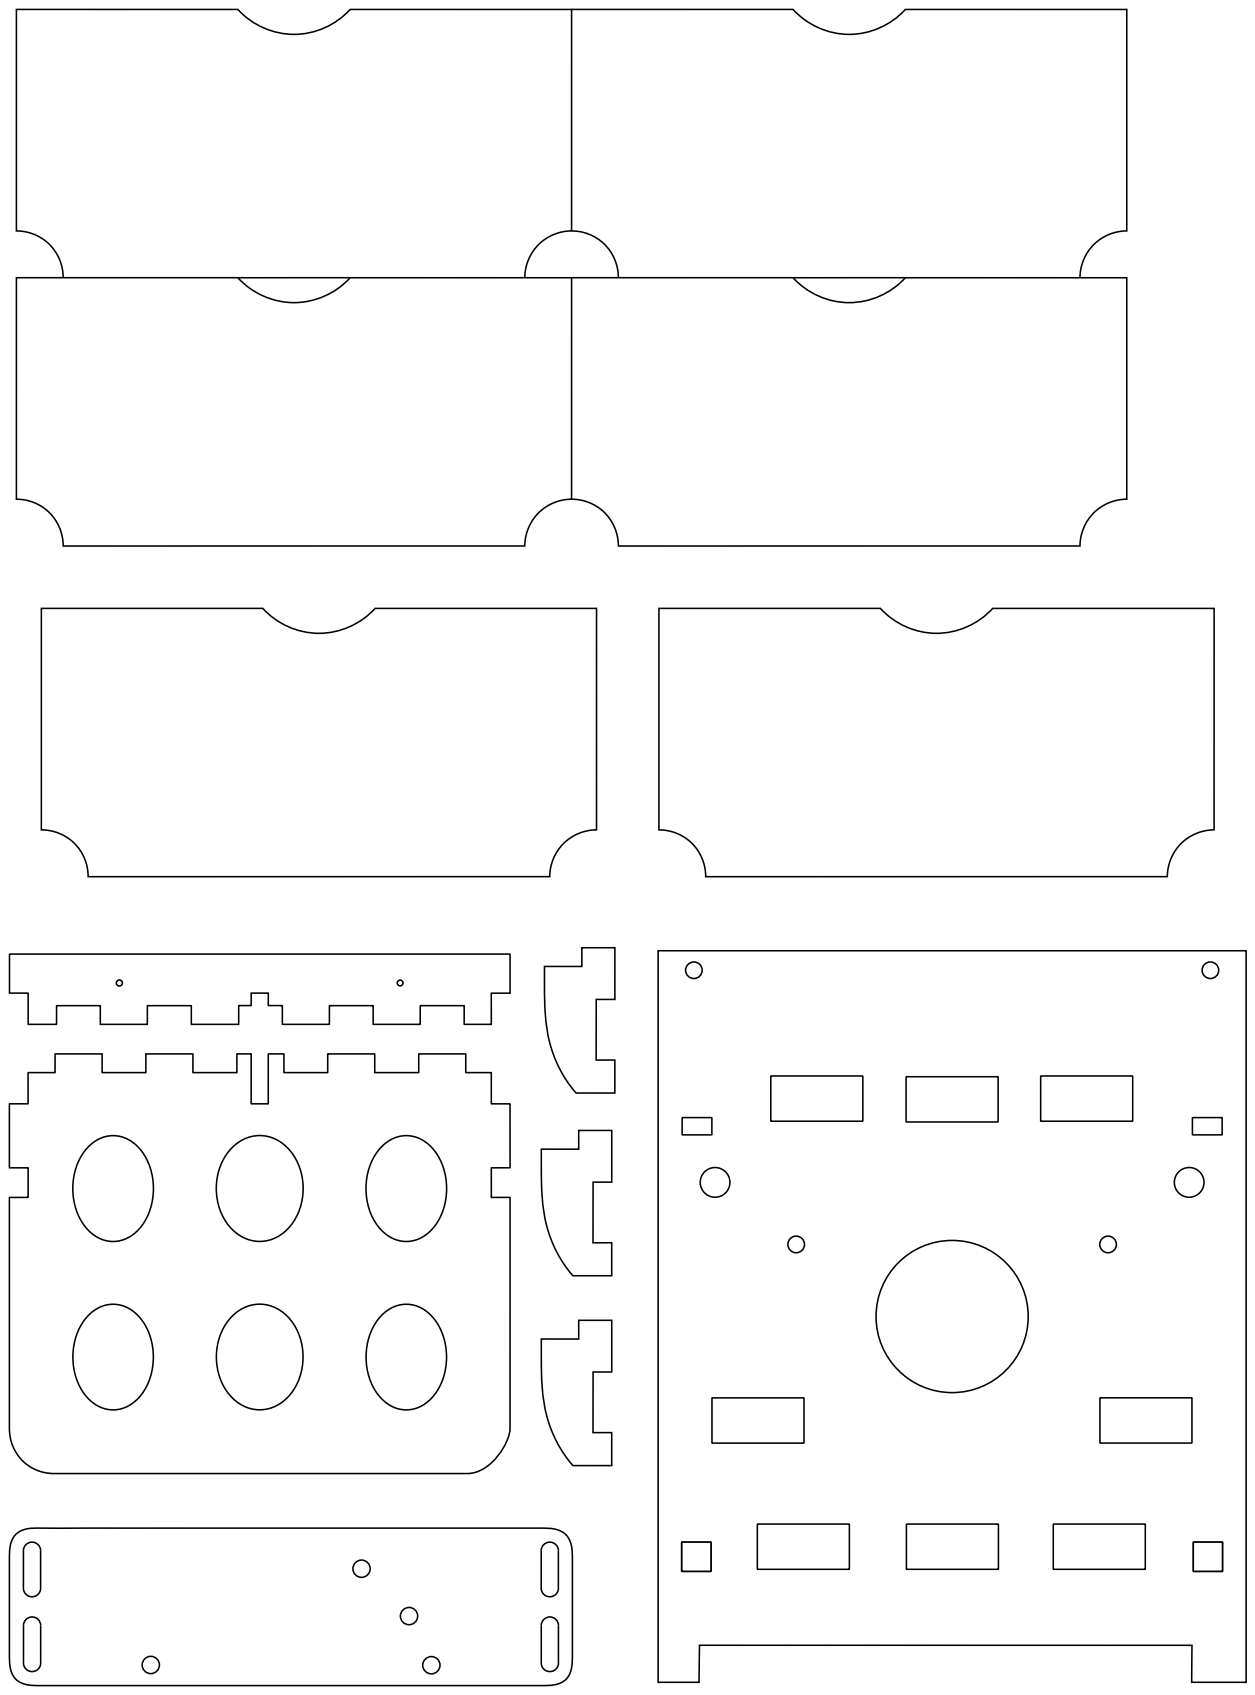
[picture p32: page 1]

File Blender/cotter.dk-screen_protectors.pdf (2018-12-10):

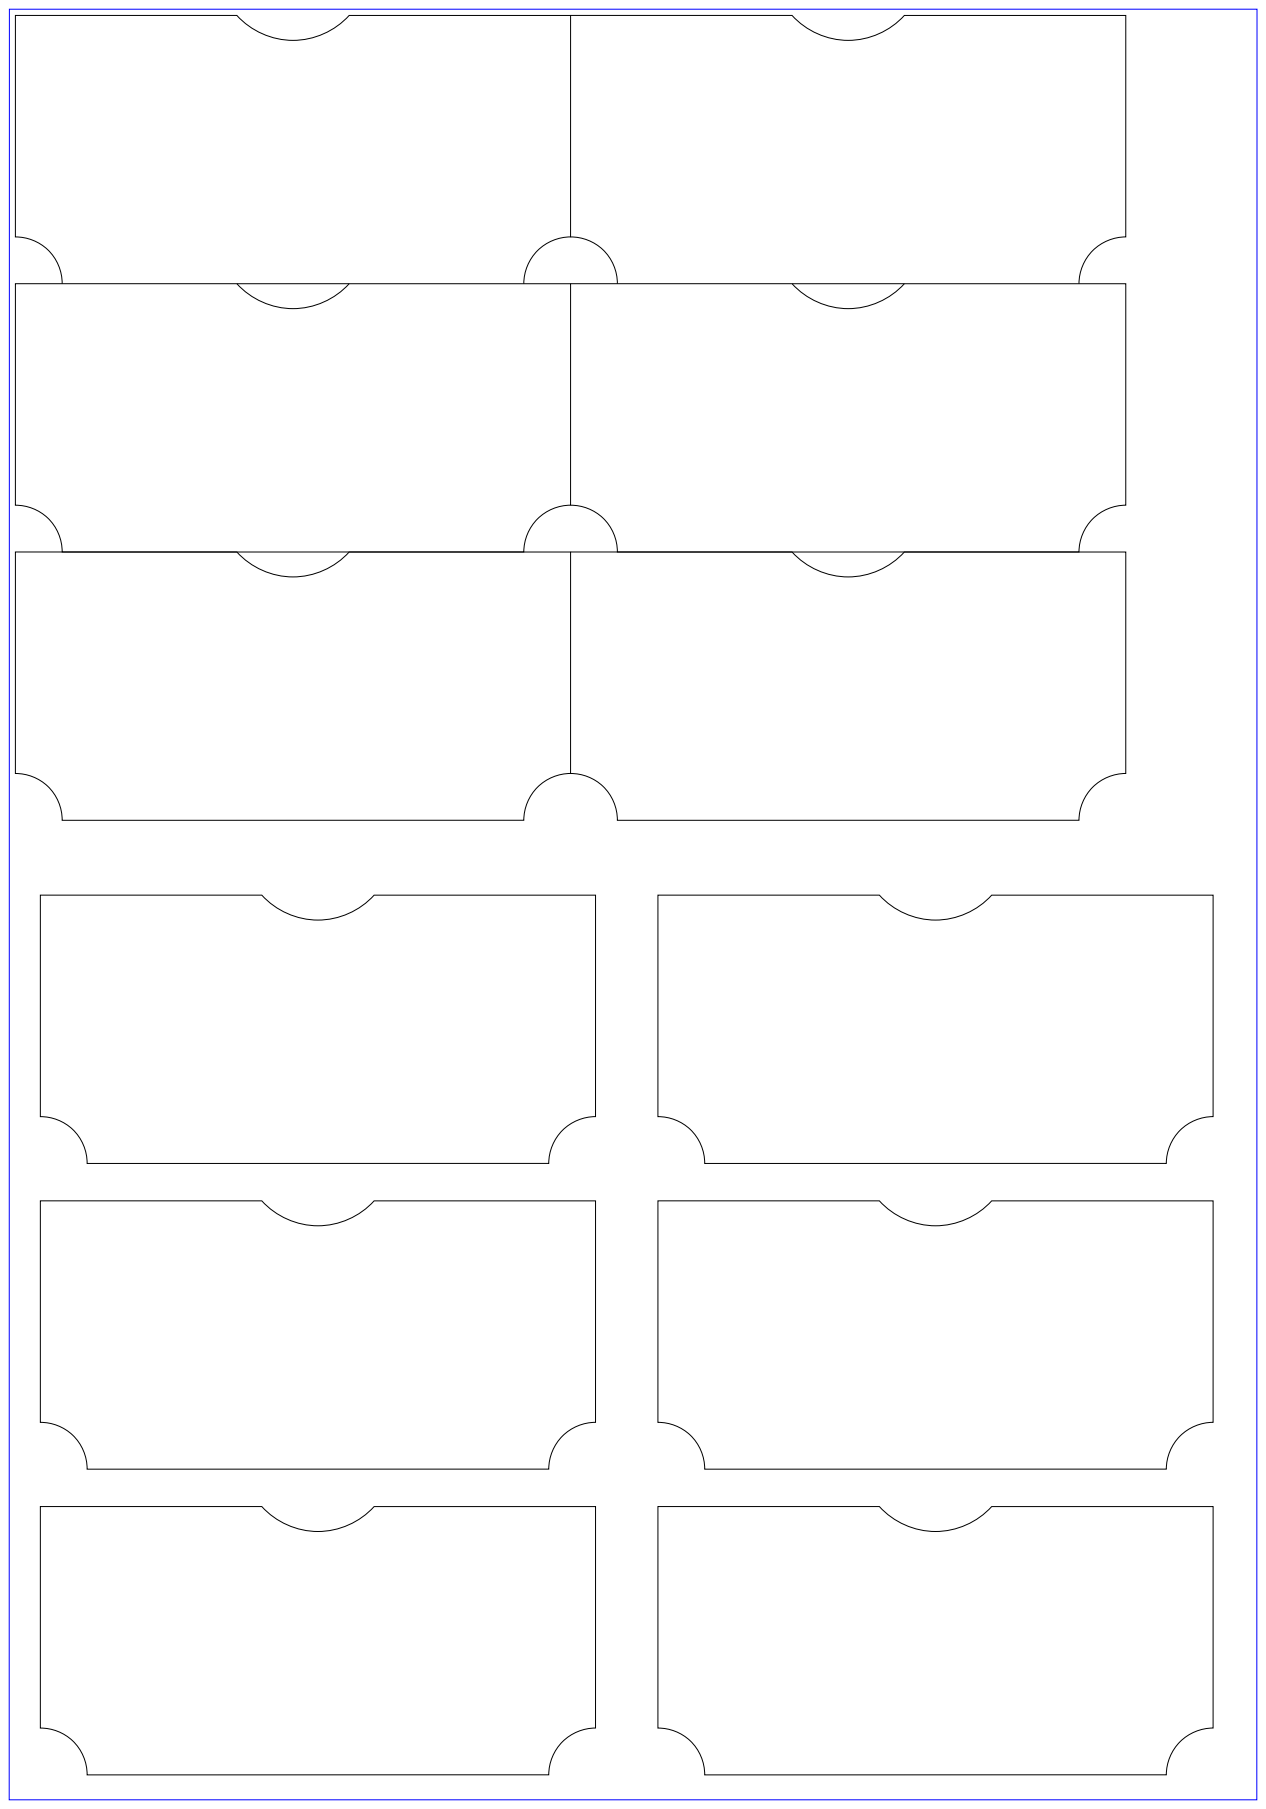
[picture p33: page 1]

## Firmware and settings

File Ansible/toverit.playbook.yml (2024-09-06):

---

- hosts: toveri
  roles:
  - role: raspberry
    tags: ['raspberry']

  - role: wiringPi
    programHome: "/home/toveri/wiringPi"
    programUser: toveri

  - role: makeProgram
    programName: "emb-gpio"
    programHome: "/home/toveri/emb-gpio"
    gitRepository: "https://github.com/Hypernova-Oy/emb-gpio.git"
    programUser: toveri
    configurations: []
    tags: ['emb-gpio']

  - role: makeProgram
    programName: "emb-rtttl"
    programHome: "/home/toveri/emb-rtttl"
    gitRepository: "https://github.com/Hypernova-Oy/emb-rtttl.git"
    programUser: toveri
    configurations:
    - file: "/etc/cron.d/emb-rtttl"
      directive: "rtttl-player"
      value: "57 8,12,14 * * *    root    /usr/local/bin/rtttl-player -R"
      create: yes
    tags: ['emb-rtttl']

  - role: makeProgram
    programName: "emb-US2066"
    programHome: "/home/toveri/emb-US2066"
    gitRepository: "https://github.com/Hypernova-Oy/emb-US2066.git"
    programUser: toveri
    configurations: []
    tags: ['emb-US2066']

  - role: makeProgram
    programName: "emb-oled"
    programHome: "/home/toveri/emb-oled"
    gitRepository: "https://github.com/Hypernova-Oy/emb-oled.git"
    programUser: toveri
    configurations:
    - file: "/etc/emb-oled/server.conf"
      directive: "^ClearTimeout "
      value: "ClearTimeout '{{hostvars[inventory_hostname]['toveri_oled_clear_timeout_s']}}'"
    - file: "/etc/emb-oled/server.conf"
      directive: "^Heartbeat_IdleBeforeHeartbeating "
      value: "Heartbeat_IdleBeforeHeartbeating '{{hostvars[inventory_hostname]['toveri_oled_heartbeat_idle_before_heartbeating_s']}}'"
    tags: ['emb-oled']

  - role: makeProgram
    programName: "SSAuthenticator"
    programHome: "/home/toveri/SSAuthenticator"
    gitRepository: "https://github.com/Hypernova-Oy/SSAuthenticator.git"
    programUser: toveri
    configurations:
    - file: "/etc/ssauthenticator/daemon.conf"
      directive: "^ApiBaseUrl "
      value: "ApiBaseUrl '{{hostvars[inventory_hostname]['toveri_api_base_url']}}'"
    - file: "/etc/ssauthenticator/daemon.conf"
      directive: "^LibraryName "
      value: "LibraryName '{{toveri_location}}'"
    - file: "/etc/ssauthenticator/daemon.conf"
      directive: "^ApiKey "
      value: "ApiKey '{{hostvars[inventory_hostname]['toveri_api_key']}}'"
    - file: "/etc/ssauthenticator/daemon.conf"
      directive: "^ApiPassword "
      value: "ApiPassword '{{hostvars[inventory_hostname]['toveri_api_password']}}'"
    - file: "/etc/ssauthenticator/daemon.conf"
      directive: "^ApiUserName "
      value: "ApiUserName '{{hostvars[inventory_hostname]['toveri_api_username']}}'"
    - file: "/etc/ssauthenticator/daemon.conf"
      directive: "^BarcodeReaderModel "
      value: "BarcodeReaderModel '{{hostvars[inventory_hostname]['toveri_barcode_reader_model']}}'"
    - file: "/etc/ssauthenticator/daemon.conf"
      directive: "^ConnectionTimeout "
      value: "ConnectionTimeout '{{hostvars[inventory_hostname]['toveri_connection_timeout']}}'"
    - file: "/etc/ssauthenticator/daemon.conf"
      directive: "^DoorOpenDuration "
      value: "DoorOpenDuration '{{hostvars[inventory_hostname]['toveri_door_open_duration']}}'"
    - file: "/etc/ssauthenticator/daemon.conf"
      directive: "^OLED_ShowCardNumberWhenRead "
      value: "OLED_ShowCardNumberWhenRead '{{hostvars[inventory_hostname]['toveri_oled_show_card_number_when_read']}}'"
    - file: "/etc/ssauthenticator/daemon.conf"
      directive: "^RequirePIN "
      value: "RequirePIN '{{hostvars[inventory_hostname]['toveri_require_pin']}}'"
    - file: "/etc/ssauthenticator/daemon.conf"
      directive: "^PINTimeout "
      value: "PINTimeout '{{hostvars[inventory_hostname]['toveri_pin_timeout']}}'"
    - file: "/etc/ssauthenticator/daemon.conf"
      directive: "^PINLength "
      value: "PINLength '{{hostvars[inventory_hostname]['toveri_pin_length']}}'"
    - file: "/etc/ssauthenticator/daemon.conf"
      directive: "^PINLengthMin "
      value: "PINLengthMin '{{hostvars[inventory_hostname]['toveri_pin_length_min']}}'"
    - file: "/etc/ssauthenticator/daemon.conf"
      directive: "^PINShowExtraLight "
      value: "PINShowExtraLight '{{hostvars[inventory_hostname]['toveri_pin_show_extra_light']}}'"
    - file: "/etc/ssauthenticator/daemon.conf"
      directive: "^RandomGreetingChance "
      value: "RandomGreetingChance '{{hostvars[inventory_hostname]['random_greeting_chance']}}'"
    - file: "/etc/ssauthenticator/daemon.conf"
      directive: "^RandomMelodyChance "
      value: "RandomMelodyChance '{{hostvars[inventory_hostname]['random_melody_chance']}}'"
    - file: "/etc/ssauthenticator/daemon.conf"
      directive: "^RandomMelodySelector "
      value: "RandomMelodySelector '{{hostvars[inventory_hostname]['random_melody_selector']}}'"
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

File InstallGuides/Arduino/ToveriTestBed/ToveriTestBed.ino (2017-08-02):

/*
 * Demo_NHD0420CW-Ax3_SPI_HW.ino
 *
 * Tutorial sketch for use of character OLED slim display family by Newhaven with Arduino Uno, without
 * using any library.  Models: NHD0420CW-Ax3, NHD0220CW-Ax3, NHD0216CW-Ax3. Controller: US2066
 * in this example, the display is connected to Arduino via SPI interface.
 *
 * Displays on the OLED alternately a 4-line message and a sequence of character "block".
 * This sketch assumes the use of a 4x20 display; if different, modify the values of the two variables
 * ROW_N e COLUMN_N.
 * The sketch uses the minimum possible of Arduino's pins; if you intend to use also /RES or /CS lines,
 * the related instructions are already present, it's sufficient to remove the comment markers.
 *
 * The circuit:
 * OLED pin 1 (Vss)    to Arduino pin ground
 * OLED pin 2 (VDD)    to Arduino pin 5V
 * OLED pin 3 (REGVDD) to Arduino pin 5V
 * OLED pin 4 to 6     to Vss ground
 * OLED pin 7 (SCLK)   to Arduino pin D13 (SCK)
 * OLED pin 8 (SID)    to Arduino pin D11 (MOSI)
 * OLED pin 9 (SOD)    to Arduino pin D12 (MISO) (optional, can be not connected)
 * OLED pin 10 to 14   to Vss ground
 * OLED pin 15 (/CS)   to Vss ground  (or to Arduino pin D2, in case of use of more than one display)
 * OLED pin 16 (/RES)  to Arduino pin Reset or VDD 5V (or to Arduino pin D3, to control reset by sw)
 * OLED pin 17 (BS0)   to Vss ground
 * OLED pin 18 (BS1)   to Vss ground
 * OLED pin 19 (BS2)   to Vss ground
 * OLED pin 20 (Vss)   to Vss ground                                                                                
 *                                                                                                                  
 * Original example created by Newhaven Display International Inc.                                                  
 * Modified and adapted to Arduino Uno 30 Mar 2015 by Pasquale D'Antini                                             
 * Modified 19 May 2015 by Pasquale D'Antini                                                                        
 * Modified to use hardware SPI 1 April 2016 by Joakim Sandström                                                    
 *                                                                                                                  
 * This example code is in the public domain.                                                                       
 */                                                                                                                 

// inslude the SPI library:                                                                                         
#include <SPI.h>                                                                                                    
#include <OneWire.h>
#include <DallasTemperature.h>


const byte ROW_N = 4;                 // Number of display rows                                                     
const byte COLUMN_N = 20;             // Number of display columns                                                  

// Assign pins
// SPI
const byte RES = 9;                 // Arduino's pin assigned to the Reset line (optional, can be always high)      
const byte CS = 10;                                                                                                  

//LED test
const byte LED_G = 4;
const byte LED_B = 3;
const byte LED_R = 2;

//DS18B20 test
const byte ONE_WIRE_BUS = 5;
// Setup a oneWire instance to communicate with any OneWire devices 
// (not just Maxim/Dallas temperature ICs)
OneWire oneWire(ONE_WIRE_BUS);
// Pass our oneWire reference to Dallas Temperature.
DallasTemperature sensors(&oneWire);


const byte TEXT[4][21] = {"1-Newhaven Display--",                                                                   
                          "2-------Test--------",                                                                   
                          "3-16/20-Characters--",
                          "4!@#$%^&*()_+{}[]<>?"
};         // Strings to be displayed

char temp1[21] = "0000.000000000000000";
char temp2[21] = "0000.000000000000000";
char TEMP_TEXT[2][21] = {"----TEMPERATURES----",
                         "----DONE TEMPERS----"};

byte new_line[4] = {0x80, 0xA0, 0xC0, 0xE0};               // DDRAM address for each line of the display
byte rows = 0x08;                     // Display mode: 1/3 lines or 2/4 lines; default 2/4 (0x08)
// _______________________________________________________________________________________
void command(byte c)                  // SUBROUTINE: PREPARES THE TRANSMISSION OF A COMMAND
{
  SPI.transfer(0x1F);

  send_byte(c);                      // Transmits the byte
}


// _______________________________________________________________________________________
void data(byte d)
{
  SPI.transfer(0x5F);

  send_byte(d);
}

// _______________________________________________________________________________________
void send_byte(byte tx_b)
{
  //Split the bytes into two and pad the last four bits with 0s
  byte tx_b1 = tx_b & 0x0F;
  byte tx_b2 = (tx_b >> 4) & 0x0F;

  //Or together the bytes
  int tx_int = (tx_b2<<8)|tx_b1;

  //transfer it
  SPI.transfer16(tx_int);
}

// _______________________________________________________________________________________

void output(void)                     // SUBROUTINE: DISPLAYS THE FOUR STRINGS, THEN THE SAME IN REVERSE ORDER
{
  unsigned long lastTime = 0;
  unsigned long temp;
  byte r = 0;                        // Row index
  byte c = 0;                        // Column index

  command(0x01);                     // Clears display (and cursor home)
  delay(2);                          // After a clear display, a minimum pause of 1-2 ms is required

  for (r = 0; r < ROW_N; r++)        // One row at a time,
  {
    command(new_line[r]);           //  moves the cursor to the first column of that line
    for (c = 0; c < COLUMN_N; c++)  // One character at a time,
    {
      data(TEXT[r][c]);            //  displays the correspondig string
    }
  }

  delay(500);                       // Waits, only for visual effect purpose

  lastTime = millis();
  command(new_line[r]);           //  moves the cursor to the first column of that line
  for (c = 0; c < COLUMN_N; c++)  // One character at a time,
  {
    data(TEMP_TEXT[0][c]);
  }
  command(new_line[r]);           //  moves the cursor to the first column of that line
  for (c = 0; c < COLUMN_N; c++)  // One character at a time,
  {
    data(temp1[c]);
  }
  command(new_line[r]);           //  moves the cursor to the first column of that line
  for (c = 0; c < COLUMN_N; c++)  // One character at a time,
  {
    data(temp2[c]);
  }
  command(new_line[r]);           //  moves the cursor to the first column of that line
  for (c = 0; c < COLUMN_N; c++)  // One character at a time,
  {
    data(TEMP_TEXT[1][c]);
  }
  temp = millis() - lastTime;
  Serial.println(temp);
  delay(1500);
}
// _______________________________________________________________________________________

void blocks(void)                     // SUBROUTINE: FILLS THE ENTIRE DISPLAY WITH THE CHARACTER "BLOCK"
{
  byte r = 0;                        // Row index
  byte c = 0;                        // Column index

  command(0x01);                     // Clear display (and cursor home)
  delay(2);                          // After a clear display, a minimum pause of 1-2 ms is required

  for (r = 0; r < ROW_N; r++)        // One row at a time,
  {
    command(new_line[r]);           //  moves the cursor to the first column of that line
    for (c = 0; c < COLUMN_N; c++)  // One character at a time,
    {
      data(0xDB);                  //  displays the character 0xDB (block)
      delay(10);                   // Waits, only for visual effect purpose
    }
    delay(100);                     // Waits, only for visual effect purpose
  }
}
// _______________________________________________________________________________________

void setup(void)                      // INITIAL SETUP
{
     /* RGB LED Setup */
     pinMode(LED_R, OUTPUT);
     digitalWrite(LED_R, HIGH);
     pinMode(LED_G, OUTPUT);
     digitalWrite(LED_G, HIGH);
     pinMode(LED_B, OUTPUT);
     digitalWrite(LED_B, HIGH);


    // DS18B20
    sensors.begin();
    


     /* OLED SPI Setup */
     pinMode(RES, OUTPUT);            // Initializes Arduino pin for the Reset line (optional)
     digitalWrite(RES, HIGH);         // Sets HIGH the Reset line of the display (optional, can be always high)
     pinMode(CS, OUTPUT);
     digitalWrite(CS, HIGH);
  SPI.begin();
  SPI.setBitOrder(LSBFIRST);
  SPI.setClockDivider(SPI_CLOCK_DIV2);
  SPI.setDataMode(SPI_MODE3);

  delayMicroseconds(200);            // Waits 200 us for stabilization purpose

digitalWrite(CS, LOW);
  if (ROW_N == 2 || ROW_N == 4)
    rows = 0x08;                    // Display mode: 2/4 lines
  else
    rows = 0x00;                    // Display mode: 1/3 lines

  command(0x22 | rows); // Function set: extended command set (RE=1), lines #
  command(0x71);        // Function selection A:
  data(0x5C);           //  enable internal Vdd regulator at 5V I/O mode (def. value) (0x00 for disable, 2.8V I/O)
  command(0x20 | rows); // Function set: fundamental command set (RE=0) (exit from extended command set), lines #
  command(0x08);        // Display ON/OFF control: display off, cursor off, blink off (default values)
  command(0x22 | rows); // Function set: extended command set (RE=1), lines #
  command(0x79);        // OLED characterization: OLED command set enabled (SD=1)
  command(0xD5);        // Set display clock divide ratio/oscillator frequency:
  command(0x70);        //  divide ratio=1, frequency=7 (default values)
  command(0x78);        // OLED characterization: OLED command set disabled (SD=0) (exit from OLED command set)

  if (ROW_N > 2)
    command(0x09);  // Extended function set (RE=1): 5-dot font, B/W inverting disabled (def. val.), 3/4 lines
  else
    command(0x08);  // Extended function set (RE=1): 5-dot font, B/W inverting disabled (def. val.), 1/2 lines

  command(0x06);        // Entry Mode set - COM/SEG direction: COM0->COM31, SEG99->SEG0 (BDC=1, BDS=0)
  command(0x72);        // Function selection B:
  data(0x0A);           //  ROM/CGRAM selection: ROM C, CGROM=250, CGRAM=6 (ROM=10, OPR=10)
  command(0x79);        // OLED characterization: OLED command set enabled (SD=1)
  command(0xDA);        // Set SEG pins hardware configuration:
  command(0x10);        //  alternative odd/even SEG pin, disable SEG left/right remap (default values)
  command(0xDC);        // Function selection C:
  command(0x00);        //  internal VSL, GPIO input disable
  command(0x81);        // Set contrast control:
  command(0x7F);        //  contrast=127 (default value)
  command(0xD9);        // Set phase length:
  command(0xF1);        //  phase2=15, phase1=1 (default: 0x78)
  command(0xDB);        // Set VCOMH deselect level:
  command(0x40);        //  VCOMH deselect level=1 x Vcc (default: 0x20=0,77 x Vcc)
  command(0x78);        // OLED characterization: OLED command set disabled (SD=0) (exit from OLED command set)
  command(0x20 | rows); // Function set: fundamental command set (RE=0) (exit from extended command set), lines #
  command(0x01);        // Clear display
  delay(2);             // After a clear display, a minimum pause of 1-2 ms is required
  command(0x80);        // Set DDRAM address 0x00 in address counter (cursor home) (default value)
  command(0x0C);        // Display ON/OFF control: display ON, cursor off, blink off

digitalWrite(CS, HIGH);
  delay(250);           // Waits 250 ms for stabilization purpose after display on

  if (ROW_N == 2)
    new_line[1] = 0xC0;             // DDRAM address for each line of the display (only for 2-line mode)
  Serial.begin(115200); //For performance measurement
}
// _______________________________________________________________________________________

void loop(void)                       // MAIN PROGRAM
{
  digitalWrite(LED_R, HIGH);
  digitalWrite(LED_G, HIGH);
  digitalWrite(LED_B, HIGH);

  sensors.requestTemperatures(); // Send the command to get temperatures
  dtostrf(sensors.getTempCByIndex(0), 20, 10, temp1);
  dtostrf(sensors.getTempCByIndex(1), 20, 10, temp2);

  digitalWrite(CS, LOW);
  output();                          // Execute subroutine "output"
  digitalWrite(CS, HIGH);
  delay(500);                       // Waits, only for visual effect purpose

  digitalWrite(LED_R, HIGH);
  digitalWrite(LED_G, LOW);
  digitalWrite(LED_B, LOW);

  digitalWrite(CS, LOW);
  blocks();                          // Execute subroutine "blocks"
  digitalWrite(CS, HIGH);
  delay(500);                       // Waits, only for visual effect purpose

  digitalWrite(LED_R, LOW);
  digitalWrite(LED_G, HIGH);
  digitalWrite(LED_B, LOW);

  digitalWrite(CS, HIGH);
  output();                          // Execute subroutine "output"
  digitalWrite(CS, LOW);
  delay(500);                       // Waits, only for visual effect purpose

  digitalWrite(LED_R, LOW);
  digitalWrite(LED_G, LOW);
  digitalWrite(LED_B, HIGH);

  digitalWrite(CS, LOW);
  blocks();                          // Execute subroutine "blocks"
  digitalWrite(CS, HIGH);
  delay(500);                       // Waits, only for visual effect purpose
}

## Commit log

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2016-08-24 change temp sensor port to the one kernel module uses
    [authenticator.sch]
2016-08-25 Fixed thermometer polarity
    [authenticator.sch]
2016-08-25 Added Blender electronic enclosure diagrams and README's
    [enclosure.blend]
2016-08-29 Fixed bugs in the electronic shcmeatics. Wrote assembly instructions and a manifest of components.
    [authenticator.sch]
2016-08-29 Added card reader guide plates to the Blender drawing
    [enclosure.blend]
2016-08-30 Added cable headers to the schematics. Added cable headers to the component manifest.
    [_saved_authenticator.sch, authenticator.kicad_pcb, authenticator.sch]
2016-08-30 Added a PCB protection plate to the model and measurements. Attach the heater there.
    [enclosure.blend]
2016-09-09 Updated bill of parts. Designing blender files to be 3d-printable from ABS-plastic.
    [enclosure.blend, enclosure_3d_printable.blend]
2016-09-09 Moved the OLED down 0.3mm in Blender
    [enclosure_3d_printable.blend]
2016-09-14 Added extra connectors to heater. Tuning he 3d-printable model.
    [_saved_authenticator.sch, authenticator.sch, enclosure_3d_printable.blend]
2016-09-15 Created the custom led housing piece.
    [enclosure_3d_printable.blend]
2016-10-28 Updated instructables, POM, Documents, Pictures.
    [Enclosure3D.stl, enclosure.blend, enclosure_3d_printable.blend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]
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2017-06-12 Toveri interior 3D model v2.
    Changed barcode reader mount to post-install, so it is easier to maintain/assemble,
    so the barcode reader is attached from the top down.
    This way one does not have to disassemble the whole Toveri to change a barcode reader.
    Moved the OLED 2mm closer to the window, since the borderline viewing angles lose
    visibility to the upper row of the OLED display.
    Removing unnecessary material from the pieces, by cutting holes in large flat surfaces.
    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
    [Enclosure3D.stl, enclosure_3d_printable_print-layout.blend]
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2017-07-06 Interior enclosure sketch created and documenting hwo to cover nasty cables and PSUs.
    [interior_enclosure.blend]
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2017-08-02 Adding Install guide and testing hardware to QA cables and components and Raspbery Pi.
    [0-pins-to-test.cfg, Toveri3D_printable.blend, Toveri3D_printable.stl]
2017-08-02 Add missing licenses to US2066 driver.
2017-08-03 Manual barcode reader configuration codes updated
    [authenticator.sch]
2017-08-08 Creating a printable PCB which can be ordered fr om a factory.
    [NHD0420CW_over_SPI.sch, authenticator.kicad_pcb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]
2017-08-08 Working with OLED PCB.
    [NHD0420CW_over_SPI.sch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]
2017-08-08 Moved front copper to back, since components are placed on top.
    Letting OLED PCB be as it is, since changing wiring would be an enormous task.
    [authenticator.kicad_pcb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]
2017-08-09 Sending these gerbers to prinel.fi
    [authenticator.kicad_pcb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]
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2017-08-11 Fixed pcb edge cut dimensions to meet factory suggestions.
    [authenticator.kicad_pcb, authenticator.sch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]
2018-12-09 Toveri V3 - KiCad Schematics
    Redone the schematics.
    Replaced the door control relay box and pcb with a Pi hat.
    This makes it more easier to make the cabling.
    Hardware PWM for the Piezo.
    Changed SPI and one-wire devices to use the hardware-enabled GPIOs.
    Moar PCB labeling.
    [authenticator.kicad_pcb, authenticator.sch]
2018-12-09 Schematic - Add missing B.Mask
    [authenticator.kicad_pcb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]
2018-12-10 laser cutting sheets + PCB sheet with multiple Toveri PCBs
    Prototyping these versions to cut costs from 3D-printing.
    PCB sheet is required/preferred by some PCB manufacturers.
    [authenticator-B.Cu.gbr, authenticator-B.Mask.gbr, authenticator-Edge.Cuts.gbr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]
2018-12-11 Blender - Updated enclosure connection railings and laser cutting sheets.
    Lowered the OLED and OLED mount by 0.5mm.
    Changed the OLED attachment pins to straight pins.
    Biggened the barcode reader inlet dimensions fo the barcode reader guide plates.
    [Toveri3D_printable_with_protplate.blend, Toveri3D_printable_with_protplate.obj]
2019-07-12 Massive overhaul where ribbon cables are replaced with Cat-cables. New enclosure and button. Various improvements.
    [Lainuri.blend, Lainuri_lasers.blend, NHD0420CW_over_SPI-2019-02-09-10-46-30.sch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]
2019-07-16 KiCad - BOM exportable from schematics. PCB ready for printing.
    [authenticator-B.Cu.gbr, authenticator-B.Mask.gbr, authenticator-Edge.Cuts.gbr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]
2019-08-14 KiCad and FreeCAD schematics for the new version.
    [NHD0420CW_over_SPI.sch, Raspi-case-A4.dxf, authenticator-bom.csv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]
2019-08-14 Added wiringPi role. Fixing install bugs.
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2019-08-30 New Toveri enclosure laser cutting profiles.
    [Raspi-case-3mm-A4.dxf, Raspi-case-4mm-A4.dxf, Raspi-case-A4.dxf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]
2019-09-23 Modify enclosure CAD design to fix minor assembly issues.
2019-09-24 Fixed FreeCAD error with barcode reading extrusion.
2019-11-04 FreeCAD - Fix enclosure back plate screw holes 4mm->6mm to fit water insulant.
2019-11-06 WiringPi - Fix to use packages instead
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2020-05-11 KiCad - Update parts with VAT0% prices to generate a storage value for components.
    [authenticator.sch, authenticator_bom.ods]
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2020-10-28 KiCad - New electronic diagrams for Pin KeyPad
    [authenticator.csv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]
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2020-10-31 KiCad - Updated electronic schematics for the new enclosure.
    [authenticator2.0.kicad_pcb]
2020-11-01 FreeCAD - Toveri enclosure for KeyPad
    [Raspi-case-3mm-A4.dxf, Raspi-case-4mm-A4.dxf, Raspi-case-A4.dxf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]
2020-11-01 Arduino - Testing with other Arduinos, like Nano, BLE Sense, IoT
    Sense crashes sporadically.
    IoT cannot flash quickly and reliably.
    Nano works quite ok.
2020-11-14 KiCad FreeCAD - Enclosure changes and PCB changes. Fix electric bugs and better assembly.
    [authenticator.csv, authenticator.sch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]
2020-11-29 KiCad - Change door opening sensor GPIO pin because ols had internal pull-up
    [authenticator.sch, authenticator2.0.kicad_pcb]
2020-12-01 KiCad - Fix short-circuited KeyPad resistor
    [authenticator.sch, authenticator2.0.kicad_pcb]
2021-01-06 KiCad - KSD471AYTA added to drive those damn relays
    Raspberry Pi apparently cannot drive relays directly.
    For some reason it worked for 6 years but not anymore with more relays.
    Too bad, had to add transistors to drive the relay coil.
    [authenticator.sch, authenticator2.0.kicad_pcb]
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2021-01-06 FreeCAD - Lid nut holder RGB-led holder megacomplex 3D-component reorder model.
    [LidNutHolder-panel.obj, LidNutHolder.obj]
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2021-02-01 KiCad - New gerbers. Fix panel layout to have more easily separateable boards.
    [authenticator2.0-B_Cu.gbr, authenticator2.0-B_Mask.gbr, authenticator2.0-Edge_Cuts.gbr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]
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2021-02-25 KiCad - Fix DS18B20+ assembly margins.
    [authenticator2.0.kicad_pcb]
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2021-07-01 KiCAD - Fix panel layout and labeling issues.
    [authenticator.sch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]
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2021-09-07 KiCad - Add inlet for enclosure screws to the PCB extension.
    [authenticator2.0-B_Cu.gbr, authenticator2.0-B_Mask.gbr, authenticator2.0-Edge_Cuts.gbr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]
2021-09-07 FreeCAD - LidNutHolder a bit less tight fitting.
    [LidNutHolder-panel.obj, LidNutHolder.obj]
2022-06-07 Updated RGB-Led text on PCB (GND to -). Updated KiCad to 6.0.5
    [authenticator2.0.kicad_pcb]
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2024-09-06 toverit.playbook - Fix ambiguity regarding config setting of commented out variables
    [toverit.playbook.yml]
